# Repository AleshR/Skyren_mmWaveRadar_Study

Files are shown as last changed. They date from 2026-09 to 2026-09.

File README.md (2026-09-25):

# Skyren mmWave Radar Study

Studie proveditelnosti levného radarového dálkoměru: **vzdálenost k plošnému
cíli (kov, beton, zeď, dřevo) do 5 m s přesností kolem 5 cm při vzájemné
rychlosti až 240 m/s**, v průměru 35 mm a za jednotky eur.

Projekt začal jako teardown laserového dálkoměru Parkside PLEM 20 A4. Ten
skončil jako slepá ulička (fázový měřák s uzavřeným ASICem) a zadání na
240 m/s pak vyřadilo i optiku jako princip.

## Závěr (revize R3)

- **24 GHz FMCW s trojúhelníkovou rampou**, jedna anténa přes Ø 35 mm
  a tištěná hyperbolická čočka (svazek ~22°, zisk ~16 dBi).
- Integrovaný radarový čip ICLegend S3KM111L z levných modulů →
  materiál **~4–7 € na kus** (cena čipu neověřená).
- **Hladké plochy** (plech, hladký beton, hoblované dřevo): chyba pod 1 cm,
  měří se kolmá vzdálenost k rovině.
- **Drsné plochy** (hrubý beton, cihla): rozhoduje speckle. Po průměrování
  přes 1,2 m přiblížení ~3 cm kolmo, ~5–6 cm při náklonu 15°.
- Vysílací výkon omezuje EIRP 20 dBm → s čočkou nejvýš 4 dBm.
- **Rozbor modulů z fotek** (LD2450, LD2451): radarový čip LD2450 nese potisk
  Hi-Link, ne ICLegend — typ čipu zatím nepotvrzený. Vysílač a přijímač
  LD2450 leží ~23 mm od sebe, jedna čočka nad oběma by ztratila ~20 dB.
- **Vývojová platforma:** LD2450 s čočkou jen nad přijímačem (konfigurace B)
  — stejný rozpočet výkonu jako cílový návrh, vyzářený výkon beze změny.
- **Praktický plán** v osmi etapách s kritérii a měřicím protokolem;
  rozhodují dvě brány: ovládnout čip vlastním firmwarem a změřit speckle
  na skutečné zdi.

Čísla pocházejí z výpočtů, simulací a fotografií, ne z měření radarem.

## Co je kde

| Cesta | Obsah |
|---|---|
| `docs/mmwave_radar_study.tex` | studie, zdroj |
| `docs/mmwave_radar_study.pdf` | vysázený dokument |
| `docs/template/` | submodul — publikační systém Skyren (`skyren.cls`) |
| `docs/datasheet/` | manuály výrobce HLK-LD2450 a HLK-LD2451 (v1.0) |
| `docs/fig/` | výřezy fotek modulů pro sazbu (JPEG z `img/`) |
| `hw/lens/lens_24ghz.scad` | parametrický model 24GHz hyperbolické čočky (OpenSCAD), i dělená a seříznutá varianta pro LD2450 |
| `sim/` | simulace v čistém Pythonu: interpolace vrcholu FFT, speckle na drsné zdi |
| `img/` | fotky: teardown Parkside PLEM 20 A4 (`IMG_2014`–`2018`), HLK-LD2450 a LD2451 (`IMG_2152`–`2155`) |

STL z `.scad` se generují lokálně a do gitu nepatří:

```bash
/Applications/OpenSCAD.app/Contents/MacOS/OpenSCAD -D n=1.62 -o lens_24ghz_PETG.stl hw/lens/lens_24ghz.scad
```

Varianty pro LD2450 (díl Rozbor, konfigurace B a C):

```bash
/Applications/OpenSCAD.app/Contents/MacOS/OpenSCAD -D n=1.62 -D cut=12 -o lens_24ghz_PETG_rx.stl hw/lens/lens_24ghz.scad
/Applications/OpenSCAD.app/Contents/MacOS/OpenSCAD -D n=1.62 -D sep=23 -o lens_24ghz_PETG_split.stl hw/lens/lens_24ghz.scad
```

## Simulace

```bash
python3 sim/interpolace.py
python3 sim/speckle.py 400
python3 sim/speckle_prumer.py 100
```

## Sazba

Vyžaduje LuaLaTeX (třída používá `fontspec`). Symlinky `docs/skyren.cls`
a `docs/fonts` ukazují do submodulu, takže se překládá přímo v `docs/`:

```bash
git submodule update --init --recursive
cd docs && lualatex mmwave_radar_study.tex && lualatex mmwave_radar_study.tex
```

Dvakrát kvůli obsahu a živému záhlaví.

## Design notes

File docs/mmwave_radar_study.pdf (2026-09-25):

SKYREN ENGINEERING

TECHNICKÁ STUDIE

# Levný radarový dálkoměr pro rychlé cíle

## Od rozebraného laserového dálkoměru k 24GHz FMCW senzoru o průměru 35 mm za jednotky eur

PRO KOHO

Vývojář elektroniky nebo konstruktér se základy vysokofrekvenční techniky (návrh patch antén, vedení, polarizace), který radar dosud nenavrhoval. Tři teoretické díly (signál, odraz, anténa) vysvětlují látku od základů i s odvozením; kdo ji zná, může číst jen souhrny na začátku a na konci dílů a pokračovat dílem Návrh.

PROJEKT
mmWave Radar

REVIZE
R3

DATUM
Září 2026

KLASIFIKACE
Interní

Skyren Engineering • 2026

MMWAVE RADAR STUDY | OBSAH

SHRNUTÍ

Vzdálenost k plošnému cíli do 5 m při vzájemné rychlosti až 240 m/s změří 24GHz

FMCW radar s trojúhelníkovou rampou, jednou anténou o průměru 35 mm a tiště-

nou čočkou za zhruba 4–7 € materiálu. Hladké povrchy změří pod 1 cm; na drsných

rozhoduje speckle — po průměrování přes 1,2 m přiblížení kolem 3 cm u kolmé zdi a 5–6 cm při náklonu 15◦
, kde zadání 5 cm splní až užší svazek. Fotky modulů HLK-

LD2450 a LD2451 ukázaly, že radarový čip nese potisk Hi-Link a že vysílač a přijímač

LD2450 leží 23 mm od sebe; vývoj proto poběží s čočkou jen nad přijímačem, která dá

stejný rozpočet výkonu jako cílový návrh. Praktický díl to převádí na osm etap s kritérii;

rozhodují dvě — ovládnout čip vlastním firmwarem a změřit speckle na skutečné zdi.

INFO JAK ČÍST TENTO DOKUMENT

Boxy se štítkem označují typ sdělení: poznámka kontext navíc, tip zkratku, úskalí častou chybu, pozor nevratný krok, příklad konkrétní výpočet. Na jeden pohled otevírá díl, co z toho plyne ho uzavírá. Mono písmo značí hodnotu nebo označení dílu, číslo v kroužku 1 součástku na fotce modulu. Revize R3 doplňuje R2 o rozbor modulů HLK z fotografií (díl Rozbor) a o praktický plán (díl Praxe), který nahradil dřívější Postup. Čísla v R3 pocházejí z výpočtů, simulací a fotografií, ne z měření radarem.

## OBSAH

Východiska — Zadání a proč ne optika | 5
2 Co jsme rozebrali | 5
3 Zadání | 6
4 Co udělá rychlost 240 m/s | 6
5 Proč ne optika | 7

MMWAVE RADAR STUDY | OBSAH
Teorie: signál — Signál FMCW | 8
7 Chirp a rozdílová frekvence | 8
8 Od vzorků ke vzdálenosti | 9
9 Rozlišení a přesnost | 10
10 Dopplerův posuv a trojúhelníková rampa | 10
11 Šum a odstup signálu od šumu | 11
12 Blízký dosah: vazba, blikavý šum a horní propust | 12
Teorie: odraz — Odraz od plošného cíle | 13
14 Tři modely odrazu | 13
15 Hladký, nebo drsný? | 14
16 Zrcadlový odraz měří kolmou vzdálenost | 14
17 Stopa svazku a posun odhadu | 15
18 Speckle | 16
19 Tenké dielektrické desky | 17
Teorie: anténa — Anténa a čočka | 18
21 Apertura, svazek a zisk | 18
22 Hyperbolická čočka | 19
23 Ztráty, odrazy a protiodrazná vrstva | 20
24 Buzení mimo osu a přesah | 20
25 Vyzářený výkon | 20

MMWAVE RADAR STUDY | OBSAH
Návrh — Doporučené řešení | 22
27 Blokové schéma | 22
28 Profil vysílání | 23
29 Rozpočet výkonu | 23
30 Rozpočet chyby | 24
31 Čočka | 25
32 Cena | 25
Rozbor — Co je uvnitř modulů HLK | 27
34 Co a jak jsme fotili | 27
35 LD2450: strana antén | 27
36 LD2450: strana součástek | 28
37 LD2451: dvě řady po osmi ploškách | 30
38 Co z toho plyne pro čočku | 32
Praxe — Od modulu k prototypu | 34
40 Plán a brány | 34
41 Pracoviště a vybavení | 35
42 Pravidla pro vysílání při vývoji | 36
43 Etapa 1: oživení s původním firmwarem | 36
44 Etapa 2: mapování desky | 37
45 Etapa 3: firmware a inicializace čipu | 38

MMWAVE RADAR STUDY | OBSAH
46 Etapa 4: surová data a kalibrace vzdálenosti | 39
47 Etapa 5: čočka a svazek | 39
48 Etapa 6: přesnost na plošných cílech | 40
49 Etapa 7: pohyb, Doppler a časování | 41
50 Etapa 8: rozhodnutí o vlastní desce | 42
PŘÍLOHA — Měřicí protokol | 43
PŘÍLOHA — Přehled vzorců | 45
PŘÍLOHA — Zvažované a zamítnuté varianty | 47
PŘÍLOHA — Zdroje a vstupní data | 49
PŘÍLOHA — Slovníček pojmů | 51

MMWAVE RADAR STUDY | CO JSME ROZEBRALI
Východiska | VÝKLAD

# Zadání a proč ne optika

BOLT NA JEDEN POHLED

Rozebraný Parkside PLEM 20 A4 je fázový měřák s uzavřeným ASICem— slepá ulička. Zadání 240 m/s pak vyřadilo optiku jako princip: limitem přestává být přesnost jednoho měření a stává se jím vzorkovací frekvence. Rozhodující pro návrh jsou ale až další dvě podmínky — cena a velikost.

## 2 CO JSME ROZEBRALI

Teardown laserového dálkoměru Parkside a důvod, proč se v něm nedá pokračovat.

Výchozím bodem byl rozebraný dálkoměr Parkside PLEM 20 A4 (model HG06724, výroba 2020/06). Měřicí modul je samostatná deska zhruba 13 × 25 mm: laserová dioda v pouzdře TO, přijímací lavinová fotodioda ve stíněné komoře, krystal a jeden ASIC v pouzdře QFN s potiskem LGSM4 / N1PA45.00-24. K hlavní desce vede osmipinový plochý spoj.

Přístroj neměří dobu letu pulzu, ale fázový posuv spojitě modulovaného svazku. Celý měřicí řetězec je uvnitř ASICu se zákaznickým označením bez veřejného datového listu. Odposlech plochého spoje by dal kontrolu nad rozhraním, ne nad měřením: frekvence i integrační čas zůstávají zadrátované v čipu. Radarové moduly HLK, na kterých stojí další vývoj, rozebírá díl Rozbor.

MMWAVE RADAR STUDY | CO UDĚLÁ RYCHLOST 240 M/S

## 3 ZADÁNÍ

Pět požadavků. Poslední dva, cena a velikost, rozhodly o návrhu nejvíc.

Zadání se během studie zpřesňovalo. Tabulka uvádí jeho konečný stav:

PARAMETR | HODNOTA | POZNÁMKA
Cíl | jeden, plošný | kov, plech, beton, zeď,
| | dřevo
Přesnost | ≈ 5 cm na 5 m | rozšíření: < 3 cm do 30 m
Rychlost | až 240 m/s | vzájemná, cíl se přibližuje
Cena | ideálně 25 €, max. 50 € | materiál na kus; priorita
| | č. 1
Velikost | kruh ∅ 35 mm, co nejmenší | priorita č. 2

Tabulka 1: Konečné zadání. Cena a velikost jsou priority, které určil zadavatel.

Důležité je, že jde o jeden cíl. Nepotřebujeme oddělit dva odrazy blízko sebe (rozlišení), stačí přesně určit polohu jednoho (přesnost). Teoretické díly ukazují, že přesnost může být o řád lepší než rozlišení.

## 4 CO UDĚLÁ RYCHLOST 240 M/S

Převod rychlosti na požadavek na vzorkovací frekvenci.

Mezi dvěma vzorky urazí cíl dráhu, kterou žádné přesnější měření neodstraní— jen vyšší frekvence:

VZORKOVACÍ FREKVENCE | PERIODA | DRÁHA MEZI VZORKY
100 Hz | 10 ms | 2,40 m
1 kHz | 1 ms | 24 cm
4 kHz | 250 µs | 6 cm
10 kHz | 100 µs | 2,4 cm

Tabulka 2: Dráha mezi dvěma vzorky při 240 m/s.

Z toho plynou tři požadavky: vzorkovací frekvence aspoň 1 kHz, integrační čas jednoho měření pod 1 ms a latence celé cesty v jednotkách milisekund. Měření staré 5 ms je 1,2 m mimo.

MMWAVE RADAR STUDY | PROČ NE OPTIKA

Times PŘESNOST Z DATOVÉHO LISTU NESTAČÍ

Údaj „± 3 cm“ v datovém listu popisuje rozptyl jednoho měření za ideálních podmínek. Při 240 m/s bývá větší chybou stáří vzorku. Tu datový list neuvede, protože závisí na vaší rychlosti — spočítejte ji z frekvence a latence.

## 5 PROČ NE OPTIKA

Jediný vyhovující optický dálkoměr je o řád dražší, než dovoluje rozpočet.

Přímé měření doby letu (dToF) splní požadavek na frekvenci jen u výjimek. LightWare SF30/D měří katalogově 0,2 až 200 m s frekvencí až 20 000 měření za sekundu. Rychlostí by zadání splnil, cenou ale patří mezi měřicí techniku, ne mezi součástky. Levné senzory (VL53Lxx, TMF8828, TF-Luna) běží na desítkách až stovkách Hz. Broadcom AFBR-S50MV85G zvládne až 3000 snímků za sekundu, ale dosah má kolem 10 m. S rozpočtem 25 € proto zbývá radar.

Flag-checkered CO Z TOHO PLYNE

Optika na tomhle zadání neselhala na přesnosti, ale na kombinaci frekvence a ceny. O dalším návrhu rozhodly cena a velikost, ne fyzikální meze měření.

MMWAVE RADAR STUDY | CHIRP A ROZDÍLOVÁ FREKVENCE
Teorie: signál | VÝKLAD

# Signál FMCW

BOLT NA JEDEN POHLED

FMCW převádí vzdálenost na kmitočet. Vzdálenost vypadne z polohy vrcholu ve spektru jedné rampy; rozlišení určuje šířka pásma, přesnost odstup signálu od šumu. Pohyb cíle posune odhad o desítky centimetrů, trojúhelníková rampa ten posuv vyruší. U blízkých cílů rozhoduje vazba vysílače do přijímače a blikavý šum.

## 7 CHIRP A ROZDÍLOVÁ FREKVENCE

Model signálu, ze kterého plyne všechno ostatní.

FMCW(frequency-modulated continuous wave) vysílá spojitý signál, jehož kmitočet lineárně roste; jedné takové rampě se říká chirp. Se sklonem S = B/T, kde B je šířka přeladění a T délka chirpu, má vysílaný signál fázi

ϕt(t) = 2π

f0t +

1/2 St²

Odraz od cíle ve vzdálenosti R přijde zpožděný o dobu letu τ = 2R/c. Směšovač vynásobí vyslaný a přijatý signál a dolní propust nechá jen rozdílovou složku:

sb(t) = A cos

2πSτ t + 2πf0τ − πSτ ²

Je to harmonický signál s rozdílovou frekvencí

fb = Sτ =

2RB
cT

a s fází 4πR/λ, která se mění už při posunu cíle o zlomek vlnové délky. Člen πSτ ² je na 5 m
pod 0,1 rad a konstantní, takže ho lze zanedbat.

MMWAVE RADAR STUDY | OD VZORKŮ KE VZDÁLENOSTI

čas

kmitočet

fb

τ

B

vyslaný chirp | přijatý odraz

Obr. 1 Princip FMCW. Vyslaný chirp (plná čára) stoupá lineárně; odraz (čárkovaně) je jeho kopie posunutá o dobu letu τ . Svislá vzdálenost mezi čarami je rozdílová frekvence fb — po celou rampu konstantní a přímo úměrná vzdálenosti cíle.

Na obr. 1 je vidět, že rozdíl mezi čarami je po celou rampu konstantní. Pro návrhový profil (B = 250 MHz, T = 10 µs) vychází fb na 1 m 167 kHz, na 5 m 833 kHz a na 8 m 1,33 MHz.

## 8 OD VZORKŮ KE VZDÁLENOSTI

Okno, FFT, doplnění nulami a interpolace vrcholu — a kolik která část přispívá k chybě.

Mezifrekvenční signál se během chirpu navzorkuje; při 4 MSPS a 10 µs to je N = 40 vzorků. Vzorkování I/Q (dva kanály posunuté o 90◦
) dává komplexní signál, který rozliší znaménko kmitočtu. To je potřeba pod 0,23 m, kde dopplerovský posuv převýší rozdílovou frekvenci (viz dále).

Vzorky se vynásobí oknem. Hannovo okno potlačí postranní laloky spektra na −31 dB, takže silná vazba vysílače do přijímače nebo druhý odraz neprosáknou do buňky cíle. Cenou je dvakrát širší hlavní lalok a šumová šířka 1,5 buňky místo jedné.

Pak následuje rychlá Fourierova transformace (FFT). Doplnění nulami ze 40 na 64 nebo 128 bodů zhustí vzorkování spektra, rozlišení ale nezlepší. Vrchol leží mezi body FFT; jeho polohu dopočítá parabolická interpolace logaritmu amplitudy ve třech bodech k − 1, k, k + 1 s hodnotami α, β, γ v dB:

δ =

1
2

·

α − γ
α − 2β + γ

, Rˆ = (k + δ) ·

c fs
2 S M
kde fs je vzorkovací frekvence a M délka FFT. Simulace s Hannovým oknem dala systematickou chybu interpolace nejvýš 2 mm pro M = 64 a 0,2 mm pro M = 128. Interpolace tedy do rozpočtu chyby nepřispívá.

MMWAVE RADAR STUDY | DOPPLERŮV POSUV A TROJÚHELNÍKOVÁ RAMPA

## 9 ROZLIŠENÍ A PŘESNOST

Rozlišení určuje šířka pásma, přesnost na jeden cíl určuje odstup signálu od šumu.

Rozlišení je nejmenší vzdálenost, na které radar oddělí dva cíle. Závisí jen na šířce přeladění:

∆R =

c
2B
Ve volném pásmu 24,00--24,25 GHz je B = 250 MHz, takže ∆R = 60 cm. Lepší rozlišení by vyžadovalo jiné pásmo: 4 GHz v pásmu 60 GHz dává 3,75 cm.

Pro jeden cíl je podstatnápřesnost. Teoretickou nejmenší chybu udáváCramér–Raovamez pro odhad kmitočtu harmonického signálu v šumu:

σR ≥

√
6
2π

·

∆R
√
SNR

≈ 0,39

∆R
√
SNR

kde SNR je odstup signálu od šumu po FFT (energie signálu za chirp k spektrální hustotě šumu). Hannovo okno s parabolickou interpolací dosahuje podle simulace σR ≈ 0,6 ∆R/

√
SNR.

TERMINAL PŘÍKLAD

Buňka 60 cm, SNR 30 dB (1000×): mez dává 0,74 cm, praktický odhad 1,1 cm, simulace 1,2 cm. Při 40 dB vychází prakticky 0,35 cm. Rozlišení 60 cm tedy přesnosti na centimetry nebrání, pokud je signálu dost a cíl je jeden.

Fáze vrcholu 4πR/λ nese ještě jemnější informaci, ale s nejednoznačností λ/2, na 24 GHz 6,2 mm. Hrubý odhad z FFT není dost přesný, aby ji rozbalil absolutně. Fáze proto dává jen relativní změnu vzdálenosti při spojitém sledování cíle.

## 10 DOPPLERŮV POSUV A TROJÚHELNÍKOVÁ RAMPA

Při 240 m/s posune pohyb cíle odhad o 23 cm. Střídání rampy nahoru a dolů ten posuv vyruší a navíc změří rychlost.

Přibližující se cíl zvýší kmitočet odrazu o dopplerovský posuv fd = 2v/λ; při 240 m/s a λ = 12,4 mm to je 38,6 kHz. U stoupající rampy se tím rozdílová frekvence zmenší, u klesající zvětší:
fb↑ = Sτ − fd, fb↓ = Sτ + fd

Převedeno na vzdálenost je každý z obou odhadů posunutý o

∆RD = | v c T λ B

což je při chirpu 10 µs 23 cm, při 25 µs už 58 cm.

MMWAVE RADAR STUDY | ŠUM A ODSTUP SIGNÁLU OD ŠUMU

čas

kmitočet

fb↑
fb↓
vyslaná rampa | odraz od přibližujícího se cíle

Obr. 2 Trojúhelníková rampa a přibližující se cíl. Odraz (čárkovaně) je zpožděný o τ a posunutý nahoru o fd. Na stoupající rampě se rozdílová frekvence zmenší, na klesající zvětší; průměr obou je bez Dopplerova posuvu.

Z dvojice odhadů R↑ = R − ∆RD a R↓ = R + ∆RD (obr. 2) plyne

R =

R↑ + R↓
2

, v =

λB
2cT
R↓ − R↑

Vzdálenost platí pro střed dvojice chirpů, tam patří i časová značka. Během jednoho chirpu se cíl posune o vT = 2,4 mm, což je zanedbatelné. Dopplerovská FFT přes více chirpů, obvyklá u automobilových radarů, tu nefunguje: s periodou chirpů kolem 25 µs je nejvyšší jednoznačná rychlost λ/4Tc ≈ 124 m/s a 240 m/s by se přetočila.

## 11 ŠUM A ODSTUPSIGNÁLU OD ŠUMU

Tepelný šum v šířce jedné buňky a proč fázový šum oscilátoru na metrech skoro nevadí.

Šum připadající na jednu buňku spektra je tepelný šum v šumové šířce okna, zvětšený o šumové číslo přijímače F:

N = kT0 ·

ENBW
T
- F | ⇒ | NdBm = −174 + 10 log10

1,5
T

+ FdB

Pro chirp 10 µs a šumové číslo 15 dB (odhad, datový list čipu nemáme) vychází N ≈ −107 dBm.

Fázový šum oscilátoru se ve směšovači z velké části odečte, protože vysílaný i referenční signál pocházejí ze stejného oscilátoru. Zbytek je úměrný 2 sin(πfmτ ), kde fm je odstup od nosné. Na 5 m je τ = 33 ns a potlačení vychází −14 dB při 1 MHz a −34 dB při 100 kHz. Na krátké vzdálenosti tedy kvalita oscilátoru rozhoduje málo.

MMWAVE RADAR STUDY | BLÍZKÝ DOSAH: VAZBA, BLIKAVÝ ŠUM A HORNÍ PROPUST

## 12 BLÍZKÝ DOSAH: VAZBA, BLIKAVÝ ŠUM A HORNÍ PRO-

## PUST

Silná vazba vysílače do přijímače, blikavý šum a velká dynamika se řeší jedním filtrem — a ten má mít pro plošný cíl sklon 20 dB na dekádu, ne 40.

S jednou anténou pro vysílání i příjem teče část vysílaného výkonu přímo do přijímače: přes konečnou izolaci vazebníku (typicky kolem 25 dB), přes odraz na anténě a přes odrazy na čočce. Tato vazba sedí u nulové rozdílové frekvence a může dosáhnout −15 až −20 dBm na vstupu přijímače. Kompresní bod přijímače integrovaného čipu neznáme; pokud je kolem −15 dBm, hrozí zahlcení. Proto je u jedné antény klíčové dobré impedanční přizpůsobení (S11 < −20 dB).

Blikavý šum (1/f) směšovače roste pod zhruba 100 kHz. Krátký chirp drží rozdílovou frekvenci i na 1 m (167 kHz) nad touto oblastí.

Výkon odrazu od plošného cíle klesá s R²
(díl Odraz od plošného cíle), amplituda tedy s 1/R, a protože fb ∝ R, klesá amplituda úměrně 1/fb. Horní propust prvního řádu s mezním kmitočtem nad pásmem měření má v pásmu zisk úměrný f, tedy +20 dB na dekádu: srovná úroveň signálu přes celý rozsah vzdáleností a současně potlačí vazbu u nulového kmitočtu. Pro bodový cíl (R⁻⁴
) by bylo potřeba +40 dB na dekádu.

Flag-checkered CO Z TOHO PLYNE

Vzdálenost dá jedna rampa a jedna malá FFT; interpolace vrcholu je přesná na milimetry. Dopplerův posuv 23 cm vyruší trojúhelníková rampa. Přesnost pak určuje odstup signálu od šumu — a u plošného cíle, jak ukáže další díl, hlavně geometrie odrazu.

MMWAVE RADAR STUDY | TŘI MODELY ODRAZU
Teorie: odraz | VÝKLAD

# Odraz od plošného cíle

BOLT NA JEDEN POHLED

Hladká plocha se chová jako zrcadlo: odraz přichází z malé skvrny kolem paty kolmice a radar změří kolmou vzdálenost na milimetry. Drsná plocha rozptyluje: přispívá celá stopa svazku, odhad se posune a náhodně kolísá (speckle). Rozhoduje drsnost vůči vlnové délce, ne materiál.

## 14 TŘI MODELY ODRAZU

Bodový cíl, zrcadlová plocha a drsná plocha mají tři různé radarové rovnice.

Bodový cíl s radarovým průřezem σ je výchozí případ radarové rovnice:

Pr =

Pt G²λ

2 σ
(4π)

3R⁴

Hladká rovina větší než první Fresnelova zóna se chová jako zrcadlo. Radar v ní vidí svůj obraz ve vzdálenosti 2R, takže

Pr =

Pt G²λ

2
|Γ|

2
(4π)

2(2R)

2

kde Γ je činitel odrazu materiálu. Odraz vzniká v první Fresnelově zóně, skvrně o poloměru
p

λR/2 kolem paty kolmice z radaru na rovinu. Na 5 m to je 18 cm, zatímco stopa svazku 22◦ má poloměr kolem 1 m. Zeď je tedy pro radar „nekonečné zrcadlo“.

Drsná rovina rozptyluje difúzně a každý kousek plochy přispívá podle koeficientu zpětného rozptylu σ

0

(m² na m² plochy). Efektivní průřez je σ = σ

0R²Ωef, kde Ωef je prostorový úhel svazku vážený dvoucestným diagramem; pro gaussovský svazek s šířkou θ3 platí Ωef = πθ²
3

/(8 ln 2). Protože zisk antény G ∝ 1/θ 2/3, vychází

Pr ∝

G
R²

Oba plošné případy tedy klesají s R²

, ne s R⁴
. U drsné plochy navíc větší anténa signál skoro nezlepší, protože užší svazek ozáří menší plochu.

MMWAVE RADAR STUDY | ZRCADLOVÝ ODRAZ MĚŘÍ KOLMOU VZDÁLENOST

## 15 HLADKÝ, NEBO DRSNÝ?

O chování plochy rozhoduje drsnost ve srovnání s vlnovou délkou. Na 24 GHz leží hranice kolem 1,5 mm.

Nerovnosti o střední výšce h rozfázují odražené vlny. Zrcadlová (koherentní) složka odrazu klesne podle Rayleighova kritéria o faktor

ρ = exp"
−
4πh cos θi
λ

2

kde θi

je úhel dopadu. Na 24 GHz to dává pokles o 1,1 dB při h = 0,5 mm, 4,4 dB při 1 mm, 18 dB při 2 mm a 40 dB při 3 mm. Obvyklá hranice je h ≈ λ/8 = 1,6 mm.

POVRCH | DRSNOST h | CHOVÁNÍ | |Γ| KOLMO
plech | 0,1 mm | zrcadlové | 1 (0 dB)
hladký beton, omítka | ≈ 0,5–1 mm | převážně zrcadlové | ≈ 0,40 (−8 dB)
hoblované dřevo | < 0,5 mm | zrcadlové | ≈ 0,17 (−15 dB)
sádrokarton | < 0,5 mm | zrcadlové | ≈ 0,25 (−12 dB)
řezané dřevo | ≈ 1–2 mm | smíšené | ≈ 0,17
hrubý beton, cihla, kámen | ≈ 2–5 mm | difúzní | —

Tabulka 3: Typické povrchy na 24 GHz. Drsnosti a permitivity jsou orientační hodnoty, ne měření.

Činitel odrazu při kolmém dopadu je Γ = (1 −

√

εr)/(1 + √
εr). Pro beton s εr ≈ 5,5 vychází 0,40, pro suché dřevo s εr ≈ 2 jen 0,17. Dřevo je tedy nejslabší zrcadlo, ale rozpočet výkonu v dílu Návrh ukáže, že i tak zbývá přes 40 dB odstupu od šumu.

## 16 ZRCADLOVÝ ODRAZ MĚŘÍ KOLMOU VZDÁLENOST

Hladká plocha nemá žádný posun od stopy svazku. Při náklonu ale měří jinou vzdálenost, než je vzdálenost v ose, a slábne.

Protože zrcadlový odraz přichází jen z první Fresnelovy zóny kolem paty kolmice, radar změří kolmou vzdálenost k rovině R⊥ = R cos α, kde α je náklon plochy vůči ose senzoru. Stopa svazku se neuplatní a chyba je daná jen šumem.

Při náklonu leží pata kolmice mimo osu svazku a odraz zeslábne podle dvoucestného diagramu. Pro svazek 22◦

je to −6 dB při 11◦

, −11 dB při 15◦

, −20 dB při 20◦ a −31 dB při 25◦ .

MMWAVE RADAR STUDY | STOPA SVAZKU A POSUN ODHADU

Hladký plech nakloněný o víc než zhruba 20◦ proto nevrátí skoro nic — nemá difúzní složku, která by zbyla.

INFO KTEROU VZDÁLENOST VLASTNĚ MĚŘÍME

Při náklonu 15◦
je na 5 m rozdíl mezi kolmou vzdáleností a vzdáleností v ose kolem 17 cm. Není to chyba měření. U hladkých ploch radar měří kolmou vzdálenost, u drsných zhruba vzdálenost v ose. Aplikace musí vědět, kterou z nich potřebuje.

## 17 STOPA SVAZKU A POSUN ODHADU

U drsné plochy přispívá celá stopa. Její zakřivení vůči radaru posune odhad za skutečnou vzdálenost.

radar

R

zeď

∆R

θ/2

Obr. 3 Stopa svazku na zdi (bokorys, úhel zveličený). Kružnice konstantní vzdálenosti (červeně) protíná zeď jen v ose; okraje stopy leží dál o ∆R. U drsné plochy padnou všechny příspěvky do jedné buňky a posunou odhad za kolmou vzdálenost.

Vzdálenost k bodu plochy ve směru (θx, θy) od osy je pro plochu nakloněnou o α kolem osy y přibližně
R(θx, θy) ≈ R
1 + θx tan α + θ

2
x

1

2 + tan² α
+

1/2 θ

2
y

Rozdíly vzdáleností ve stopě jsou mnohem menší než buňka 60 cm, takže vrchol FFT leží ve výkonově váženém průměru vzdáleností. Pro gaussovský dvoucestný diagram s rozptylem σ

2
θ = θ

2/3/(16 ln 2) v každé ose lineární člen vypadne a zbude posun od stopy svazku

b = R σ²
θ

(1 + tan² α) = R θ²
3
16 ln 2

(1 + tan² α)

MMWAVE RADAR STUDY | SPECKLE

(obr. 3). U kolmé zdi se simulace od vzorce liší o méně než desetinu, u nakloněné do pětiny, zčásti kvůli statistickému rozptylu simulace.

HPBW | POSUN NA 5 M | POSUN NA 30 M
42◦ | 24 cm | 1,45 m
22◦ | 6,6 cm | 40 cm
14◦ | 2,7 cm | 16 cm
10◦ | 1,4 cm | 8,2 cm

Tabulka 4: Posun odhadu od stopy svazku pro drsnou zeď kolmo k ose. Hodnota je deterministická a odečítá se kalibrací.

Posun je pro známou vzdálenost a svazek spočitatelný, takže se odečte. Náklon ho zvětší o tan² α, při 15◦ o 7 %. Zbytek po kalibraci je na 5 m se svazkem 22◦ kolem 0,5 cm z náklonu, k tomu neznámý příspěvek toho, že σ

0 závisí na úhlu dopadu a váží stopu nesymetricky. Počítáme s celkem kolem 1 cm, ale ověřené to není.

## 18 SPECKLE

Příspěvky drsné plochy se sčítají s náhodnými fázemi. Odhad vzdálenosti proto kolísá, a u nakloněné plochy hodně.

Každý kousekdrsné plochy vrací vlnu s náhodnou fází. Jejich součet má náhodnou amplitudu i náhodnou polohu vrcholu ve spektru; tomuto jevu se říká speckle. Střední hodnota odhadu je posun b z předchozí sekce, kolem ní odhad kolísá zhruba o efektivní rozptyl vzdáleností ve stopě

sR ≈ R σθ

q
σ

2

θ + tan² α

U kolmé plochy je sR = b, u nakloněné převládne lineární člen R σθ tan α a kolísání vzroste několikanásobně. Když amplituda odrazu náhodně klesne (hluboký útlum), poloha vrcholu ujede výrazně víc; takové měření je lepší zahodit.

HPBW | NÁKLON | SIMULACE | MODEL sR
22◦ | 0
| ◦ | 7,1 cm | 6,7 cm
22◦ | 15◦ | 15,8 cm | 16,8 cm
14◦ | 0
| ◦ | 3,0 cm | 2,7 cm
14◦ | 15◦ | 10,6 cm | 10,2 cm
10◦ | 0
| ◦ | 1,3 cm | 1,4 cm
10◦ | 15◦ | 7,2 cm | 7,2 cm

MMWAVE RADAR STUDY | TENKÉ DIELEKTRICKÉ DESKY

Tabulka 5: Kolísání jednoho měření na drsné zdi ve 5 m. Simulace Monte Carlo s vyřazením 10 % nejslabších měření, srovnaná s modelem.

Kolísání pomůže jen průměrování přes nezávislé realizace speckle. Při přibližování se mění relativní fáze příspěvků a nová realizace vznikne zhruba po každých

δR ≈

λR
4 sR

přiblížení, na 5 m u kolmé zdi a svazku 22◦ po 24 cm. Průměr přes dráhu přiblížení L má kolísání

σprům ≈

r
sR λR
4L
Pro L = 1,2 m (5 ms při 240 m/s) dává model 2,9 cm u kolmé zdi a 4,7 cm při náklonu 15◦ ;
simulace přibližování dala 2,3 cm a 5,8 cm.

Times PRŮMĚRUJE SE DRÁHA, NE ČAS

Speckle se obnovuje pohybem, ne časem. Při 240 m/s dá 5 ms dost nezávislých měření, při 10 m/s by stejné okno vystačilo jen na 5 cm dráhy a kolísání by zůstalo skoro celé. Když senzor stojí, je speckle zamrzlý a chyba se stane pevnou chybou daného místa. Pásmo 250 MHz je navíc příliš úzké na to, aby pomohlo střídání kmitočtu.

## 19 TENKÉ DIELEKTRICKÉ DESKY

Dřevěná deska nebo sádrokarton odrážejí z přední i zadní strany a oba odrazy padnou do jedné buňky.

Část vlny projde do materiálu s nízkou permitivitou a odrazí se od zadní strany. Ta se radaru jeví posunutá o √
εr d; pro 2cm překližku s εr ≈ 2 o 2,8 cm. Oba odrazy leží v jedné buňce a interferují podle tloušťky desky, takže vrchol se posune o část této vzdálenosti. Útlum ve vlhkém dřevě zadní odraz zeslabí. Počítáme s posunem řádově 1 cm, ověřené to není.

Flag-checkered CO Z TOHO PLYNE

Hladké plochy dávají zrcadlový odraz bez posunu od stopy: chyba pod centimetr, měřená je kolmá vzdálenost. Nejhorším cílem pro přesnost je drsná nakloněná plocha: jedno měření kolísá o 15 cm i víc a pomůže jen užší svazek a průměrování přes dráhu přiblížení.

MMWAVE RADAR STUDY | APERTURA, SVAZEK A ZISK
Teorie: anténa | VÝKLAD

# Anténa a čočka

BOLT NA JEDEN POHLED

Šířka svazku je daná průměrem apertury ve vlnových délkách, takže na 24 GHz se do ∅ 35 mm vejde jeden svazek kolem 22◦
. Plastová hyperbolická čočka ho vytvoří z malé antény levně. Zisk čočky ale omezuje vysílací výkon: vyzářený výkon v pásmu 24 GHz nesmí přesáhnout 100 mW.

## 21 APERTURA, SVAZEK A ZISK

Tři vztahy, které určují velikost senzoru.

Pro kruhovou aperturu o průměru D platí přibližně

θ3 ≈ (58 až 70) λ
D

, G ≈ η

πD
λ

2
, Rff =

2D²

λ

Šířka svazku θ3 ve stupních platí s koeficientem 58 pro rovnoměrné osvětlení, se 70 pro osvětlení klesající k okraji. Činitel využití apertury η bývá 0,5–0,6. Vzdálenost Rff je začátek dalekého pole. Pro ∅ 35 mm na 24 GHz vychází θ3 ≈ 21–23◦
, G ≈ 16 dBi a Rff ≈ 20 cm.
PÁSMO | λ | ∅ PRO 22◦ | ∅ PRO 10◦
24 GHz | 12,4 mm | ≈ 30–35 mm | ≈ 75 mm
60 GHz | 5,0 mm | ≈ 10–12 mm | ≈ 30–35 mm

Tabulka 6: Průměr apertury podle pásma a požadované šířky svazku.

Do ∅ 35 mm se tedy na 24 GHz vejde právě jeden svazek kolem 22◦
. Proto návrh používá
jednu anténu pro vysílání i příjem. Dvě antény vedle sebe by měly svazek zhruba 23×42◦ a podle tabulky posunů v dílu Odraz od plošného cíle několikanásobně větší posun i kolísání. Svazek 10◦
, který by pomohl na drsných nakloněných plochách, se do ∅ 35 mm vejde jen na 60 GHz.

MMWAVE RADAR STUDY | HYPERBOLICKÁ ČOČKA

## 22 HYPERBOLICKÁ ČOČKA

Tvar plochy plyne z Fermatova principu: všechny paprsky z ohniska musí mít za čočkou stejnou optickou dráhu.

Zdroj leží v ohnisku ve vzdálenosti f před vrcholem čočky. Paprsek, který dopadne na plochu v bodě (x, r), má urazit stejnou optickou dráhu jako paprsek v ose, aby za rovnou plochou vyšla rovinná vlna. Uvnitř materiálu s indexem lomu n se dráha násobí n, takže

p
x

2 + r

2 = f + n (x − f)

Po dosazení x = f + z, kde z je výška profilu nad vrcholem, vyjde

r

2 = 2 (n − 1) f z + (n

2 − 1) z

2

tedy hyperbola. Parametrický model podle tohoto vztahu je v hw/lens/lens_24ghz.scad.

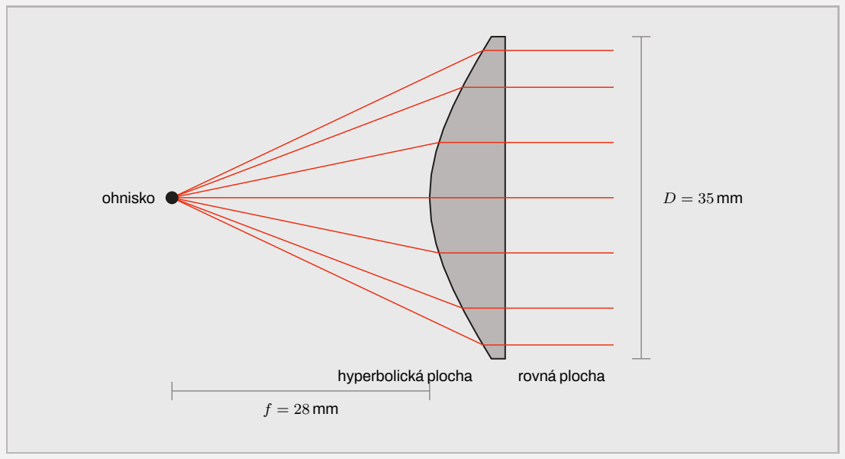
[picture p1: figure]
ohnisko; hyperbolická plocha; rovná plocha

Obr. 4 Hyperbolická čočka z PETG (n = 1,62, f = 28 mm, ∅ 35 mm), zvětšeno. Paprsky z ohniska se na hyperbolické ploše lámou tak, že za čočkou běží rovnoběžně.

Obr. 4 ukazuje hlavní vlastnost: hyperbolická plocha míří k anténě, rovná plocha k cíli. Fázový střed antény musí ležet přesně v ohnisku. Posun o pár milimetrů podél osy svazek rozostří, posun napříč ho vychýlí.

MMWAVE RADAR STUDY | VYZÁŘENÝ VÝKON

## 23 ZTRÁTY, ODRAZY A PROTIODRAZNÁ VRSTVA

Tištěný plast má na 24 GHz zanedbatelné ztráty. Víc vadí odrazy na plochách, které se vracejí do přijímače.

Na každé ploše se odrazí podíl výkonu

|Γ|

2 =

n − 1

n + 12

pro PETG 5,6 % (−12,5 dB), což dělá 0,25 dB ztráty na plochu. Odražená vlna se vrací do antény a přidá se k vazbě vysílače do přijímače. Dielektrické ztráty jsou

αdB ≈ 27,3

n tan δ
λ0
na jednotku délky; pro PETG s tan δ ≈ 0,01 (odhad) to je 0,036 dB/mm, ve středu čočky tlusté 8 mm tedy kolem 0,3 dB.

Odrazy odstraní protiodrazná vrstva tloušťky λ0/4nm s indexem lomu nm =

√
n. Pro PETG
vychází nm = 1,27 (εr = 1,62) a tloušťka 2,4 mm. Tisk nabízí levný trik: vrstvu vytisknout se sníženou výplní. Při lineárním směšování permitivit s vzduchem odpovídá εr = 1,62 výplni kolem 38 %. Je to orientační výpočet; skutečnou permitivitu je třeba změřit.

## 24 BUZENÍ MIMO OSU A PŘESAH

Anténa mimo ohnisko vychýlí svazek; záření, které čočku mine, svítí do stran.

Posune-li se fázový střed antény o d napříč osou, svazek se vychýlí zhruba o úhel d/f na opačnou stranu. U modulu s oddělenou vysílací a přijímací anténou se tak jejich svazky pod jednou čočkou rozejdou. Při rozestupu 10 mm a f = 28 mm to je ± 10◦
: společný svazek se
zúží a ztratí několik dB. LD2450 má rozestup 23 mm (díl Rozbor), tedy kolem ± 20◦ a ztrátu kolem 20 dB. Na vlastní desce s jednou anténou tento problém odpadá.

Okraj čočky vidí anténa pod úhlem arctan(D/2f) = 32◦
. Co vyzáří pod větším úhlem, čočku mine (přesah) a svítí do stran, kde vrací odrazy od bližších ploch. Mezi anténu a čočku proto patří trubka, zevnitř vodivá nebo s absorbérem.

## 25 VYZÁŘENÝ VÝKON

Zisk čočky se počítá do vyzářeného výkonu. S 16 dBi smí vysílač dávat nejvýš 4 dBm.

V pásmu 24,00–24,25 GHz je pro zařízení krátkého dosahu povolený ekvivalentní izotropně vyzářený výkon (EIRP) 100 mW, tedy 20 dBm (ERC/REC 70-03, příloha 1; aktuální znění je

MMWAVE RADAR STUDY | VYZÁŘENÝ VÝKON

třeba ověřit). EIRP je součet vysílacího výkonu a zisku antény, takže s čočkou 16 dBi smí vysílač dávat nejvýš 4 dBm. Hotový modul, který je certifikovaný s vlastní anténou, může po přidání čočky limit překročit. Vysílací výkon je pak nutné ve firmwaru snížit. Rozpočet výkonu v dílu Návrh už s 4 dBm počítá.

Flag-checkered CO Z TOHO PLYNE

Čočka ∅ 35 mm dá na 24 GHz svazek kolem 22◦ a zisk 16 dBi za cenu plastu. Její tvar plyne přímo z Fermatova principu, ztráty jsou zanedbatelné a odrazy lze potlačit vrstvou s řidší výplní. Zisk ale snižuje povolený vysílací výkon na 4 dBm.

MMWAVE RADAR STUDY | BLOKOVÉ SCHÉMA
Návrh | REFERENCE

# Doporučené řešení

BOLT NA JEDEN POHLED

Pásmo 24 GHz, jedna anténa s čočkou ∅ 35 mm, integrovaný radarový čip s trojúhelníkovou rampou a levný mikrokontrolér. Tabulky uvádějí profil vysílání, rozpočet výkonu, rozpočet chyby, čočku a cenu. Hodnoty čipu, které nejsou ověřené, jsou takto označené.

## 27 BLOKOVÉ SCHÉMA

Čtyři bloky: čočka s anténou, vazebník, radarový čip a mikrokontrolér.

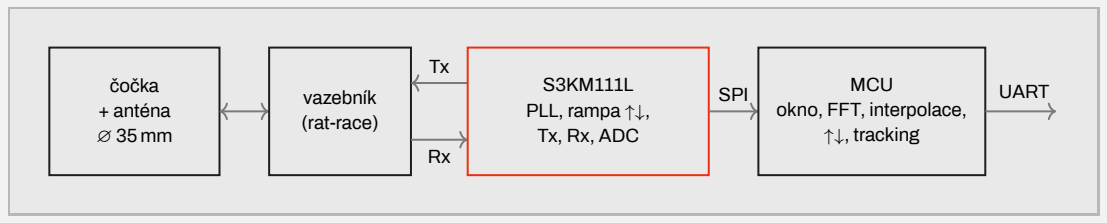
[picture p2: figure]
čočka + anténa ∅ 35 mm; vazebník (rat-race); S3KM111L PLL, rampa ↑↓, Tx, Rx, ADC; SPI; MCU; okno, FFT, interpolace, ↑↓, tracking; UART

Obr. 5 Blokové schéma senzoru. Vazebník spojuje vysílač a přijímač čipu do jedné antény; čip vzorkuje mezifrekvenční signál a mikrokontrolér z něj počítá vzdálenost.

Obr. 5 ukazuje cílovou vlastní desku. Při vývoji na hacknutém modulu LD2450 místo vazebníku a jedné antény slouží jeho oddělené antény a čočka sedí jen nad přijímačem (díl Rozbor, konfigurace B).

MMWAVE RADAR STUDY | ROZPOČET VÝKONU

## 28 PROFIL VYSÍLÁNÍ

Cílový profil pro dosah do 5 m.

PARAMETR | HODNOTA | DŮVOD
Šířka přeladění | 250 MHz | celé volné pásmo 24 GHz
Rampa | trojúhelníková | vyruší Dopplerův posuv
Délka chirpu | 10 µs | fb nad pásmem blikavého
| | šumu
fb na 1 / 5 / 8 m | 167 kHz / 833 kHz /
| 1,33 MHz
Vzorkování | 4 MSPS, I/Q | 40 vzorků, Hann, FFT 64
| | nebo 128
Vysílací výkon | ≤ 4 dBm | EIRP 20 dBm se ziskem
| | 16 dBi
Výstup | 1 měření na pár chirpů | 4–10 kHz podle čipu a MCU

Tabulka 7: Cílový profil. Zda ho integrovaný čip umí nastavit, zejména délku chirpu, zatím nevíme.

Integrovaný čip ICLegend S3KM111L podle databriefu umí trojúhelníkovou rampu a až 8 000 chirpů za sekundu, tedy kolem 4 kHz měření. Pokud ale nepodporuje chirp výrazně kratší než periodu 125 µs, klesne rozdílová frekvence na 1 m na desítky kHz a měření pod 1–2 m se zhorší. Na 5 m to nevadí.

## 29 ROZPOČET VÝKONU

Na 5 m je signálu dost i pro nejslabší povrch.

CÍL | PŘIJATÝ VÝKON | SNR PO FFT
plech, zrcadlově | −51 dBm | 56 dB
hladký beton, zrcadlově | −59 dBm | 48 dB
sádrokarton, zrcadlově | −63 dBm | 44 dB
suché dřevo, zrcadlově | −66 dBm | 41 dB
drsný povrch, σ
0 = −10 dB | −77 dBm | 30 dB
drsný povrch, σ
0 = −20 dB | −87 dBm | 20 dB

Tabulka 8: Rozpočet výkonu na 5 m. Vysílač 4 dBm, čočka 16 dBi, vazebník 3,5 dB v každém směru, šum −107 dBm na buňku (šumové číslo 15 dB je odhad).

MMWAVE RADAR STUDY | ROZPOČET CHYBY

Mezi nejsilnějším případem (plech zblízka) a nejslabším (drsný povrch na 5 m) je přes 60 dB. K tomu vazba vysílače do přijímače kolem −15 dBm. Proto horní propust s +20 dB na dekádu a podle potřeby řízení zesílení.

## 30 ROZPOČET CHYBY

Na hladkých plochách pod centimetr, na drsných rozhoduje speckle a průměrování přes dráhu přiblížení.

ZDROJ CHYBY | HLADKÝ | DRSNÝ, KOLMO | DRSNÝ, 15◦
šum, jedno měření | 0,1–0,4 cm | 1,9 cm | 1,9 cm
posun od stopy po kalibraci | 0 | ≈ 1 cm | ≈ 1–1,5 cm
speckle, jedno měření | 0 | 7 cm | 16 cm
Dopplerův posuv po průměru ramp | ≈ 0 | ≈ 0 | ≈ 0

celkem, jedno
měření
< 0,5 cm | ≈ 7 cm | ≈ 16 cm

celkem po
průměrování
< 0,5 cm | ≈ 3 cm | ≈ 5–6 cm

Tabulka 9: Rozpočet chyby na 5 m se svazkem 22◦ . Hodnoty „po průměrování“ platí pro průměr přes 1,2 m přiblížení (5 ms při 240 m/s), šum pro drsný povrch s σ

0 = −15 dB. Jde o výpočty a simulace, ne o měření.

Zadání 5 cm tedy splní hladké plochy vždy a drsné plochy kolmo k ose po průměrování. Drsná plocha nakloněná o 15◦ vychází na hranici. Pomohl by užší svazek (s 10◦ vychází model na 3 cm), ten se ale do ∅ 35 mm na 24 GHz nevejde. Druhou možností je delší dráha průměrování, pokud to aplikace dovolí.

MMWAVE RADAR STUDY | CENA

## 31 ČOČKA

Parametry pro tisk a obrábění.

MATERIÁL | n | TLOUŠŤKA VE
| | STŘEDU

VÝŠKA OD ANTÉNY

HDPE | 1,52 | 9,3 mm | 37 mm
PTFE | 1,45 | 10,3 mm | 38 mm
PETG (tisk, 100 % výplň) | ≈ 1,62 | 8,2 mm | 36 mm
PLA (tisk, 100 % výplň) | ≈ 1,65 | 7,9 mm | 36 mm

Tabulka 10: Čočka ∅ 35 mm, ohnisková vzdálenost 28 mm, okraj 1,5 mm. Indexy lomu tištěných plastů jsou orientační.

Očekávaná šířka svazku je 21–23◦
, zisk kolem 16 dBi a daleké pole začíná zhruba ve 20 cm. Pro první prototypy stačí tisk z PETG; pro další iterace je lepší HDPE se známými vlastnostmi a nulovými ztrátami.

## 32 CENA

Materiál na kus při 500 kusech. Rozhoduje radarový čip.

VARIANTA | RADAROVÝ ČIP | CELKEM

Integrovaný SoC
(doporučeno)

S3KM111L, ≈ 1–2 €
(neověřeno)

≈ 4–7 €

Záloha s vlastním
front-endem
| BGT24MTR11, ≈ 10 € | ≈ 15 €

60 GHz s anténou
v pouzdře
| Acconeer A121, ≈ 9 $ | ≈ 10–12 €

Tabulka 11: Varianty materiálu na kus. Cena čipu S3KM111L je odhad z cen hotových modulů, ne nabídka.

Integrovaný čip obsahuje vysílač, přijímač, PLL, generátor rampy a ADC, takže odpadá rychlý ADC, generátor rampy i teplotně kompenzovaný krystal. Rampa z PLL je lineární, takže odpadá i kalibrace linearity při výrobě. Stačí levnýmikrokontrolér, který přijímá data a počítámalé

MMWAVE RADAR STUDY | CENA

FFT. Anténa může být na FR4 nebo levném PTFE laminátu F4B: ztráty 2–3 dB a rozladění kvůli toleranci permitivity jsou při rezervě přes 20 dB přijatelné.

Kterou vzdálenost potřebuješ?

v ose senzoru | k nejbližšímu povrchu

úzký svazek ≈ 22◦

24 GHz + čočka ∅ 35, 4–7 €

široký svazek stačí

A121 bez čočky, ≈ 8×8 mm

Obr. 6 Volba varianty. O velikosti rozhoduje, kterou vzdálenost aplikace potřebuje.

Široký svazek přirozeně měří nejbližší bod plochy. Pokud aplikaci stačí nejkratší vzdálenost k povrchu, úzký svazek není potřeba a velikost určí jen čip (obr. 6). Pro nejbližší bod je ale potřeba jemné rozlišení, aby šla přesně najít náběžná hrana odrazu — proto v pravé větvi 60 GHz, ne 24 GHz s buňkou 60 cm.

Flag-checkered CO Z TOHO PLYNE

Doporučená varianta stojí na integrovaném 24GHz čipu za jednotky eur, jedné anténě přes ∅ 35 mm a tištěné čočce. Na hladkých plochách měří pod centimetr, na drsných kolmých po průměrování kolem 3 cm. Drsné nakloněné plochy a rozšíření na 3 cm do 30 m potřebují užší svazek, v tomto průměru tedy 60 GHz.

MMWAVE RADAR STUDY | LD2450: STRANA ANTÉN
Rozbor | VÝKLAD

# Co je uvnitř modulů HLK

BOLT NA JEDEN POHLED

Fotky obou stran HLK-LD2450 a HLK-LD2451 potvrdily uspořádání 1T2R a pouzdro QFN-32, ne ale typ čipu: radarový čip LD2450 nese potisk Hi-Link. Vysílač a přijímač LD2450 leží 23 mm od sebe, takže jedna čočka nad oběma by ztratila kolem 20 dB. Čočka jen nad přijímačem dá naopak stejný rozpočet výkonu jako cílový návrh a nemění vyzářený výkon.

## 34 CO A JAK JSME FOTILI

Rozměry pocházejí z fotografií, ne z měřidla. Nejistota je kolem 5 %, u rozestupu antén tedy ± 1 mm.

Oba moduly jsme nafotili telefonem shora, každý z obou stran (snímky IMG_2152 až IMG_2155 ve složce img/, výřezy pro sazbu v docs/fig/). Měřítko dává obrys desky podle rozměrů výrobce, 44 × 15 mm u LD2450 a 70 × 35 mm u LD2451; u LD2450 vychází kolem 40 obrazových bodů na milimetr. Nejistotu přidává perspektiva a zaoblené rohy desky.

Potisky čipů jsou vypálené laserem a v rovném světle skoro splývají s pouzdrem. Čitelný byl jen potisk radarového čipu LD2450, a to až po otočení výřezu a zvýšení kontrastu. Ostatní přečte až makrosnímek s bočním světlem (díl Praxe, etapa 2).

## 35 LD2450: STRANA ANTÉN

Jeden vysílač a dva přijímače po dvou ploškách, mezi nimi radarový čip s potiskem Hi-Link.

MMWAVE RADAR STUDY | LD2450: STRANA SOUČÁSTEK

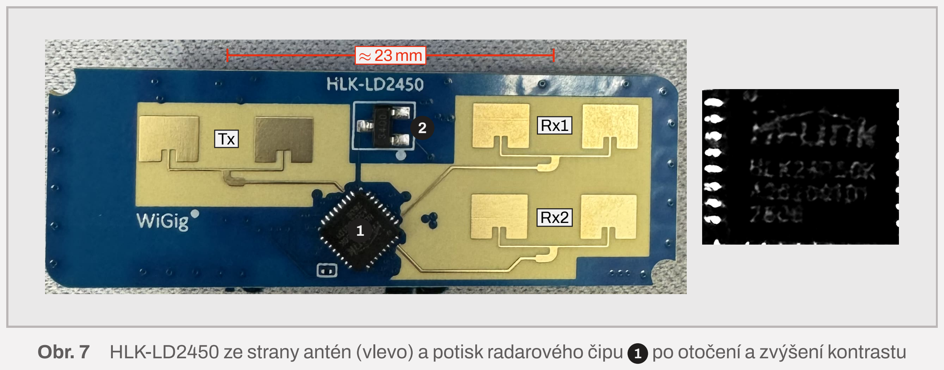
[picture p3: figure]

Obr. 7 HLK-LD2450 ze strany antén (vlevo) a potisk radarového čipu 1 po otočení a zvýšení kontrastu (vpravo). Vysílač Tx tvoří dvě plošky; přijímače Rx1 a Rx2 po dvou ploškách leží 6,4 mm nad sebou. Středy Tx a Rx1 dělí asi 23 mm.

Na obr. 7 je vidět uspořádání 1T2R, které uvádí výrobce. Antény jsou plošky (patch): obdélníky mědi nad zemní vrstvou desky, které rezonují na délce kolem půl vlnové délky v laminátu. Vlevo je vysílač, dvě plošky 4,1 × 3,1 mm s roztečí 8,1 mm na jednom vedení. Vpravo jsou dva přijímače, každý ze dvou plošek 3,8 × 3,1 mm s roztečí 7,6 mm. Řady přijímačů leží 6,4 mm nad sebou, zhruba půl vlnové délky ve vzduchu: z rozdílu fází mezi nimi modul počítá úhel cíle napříč deskou. Plošky jsou napájené od kratší hrany, takže polarizace míří podél kratší strany desky.

Dvojice plošek dává svazek kolem 40◦ podél delší strany desky a kolem 90◦ napříč, se ziskem kolem 9 dBi. Jsou to odhady z geometrie, ne měření. Anténní pole je bez nepájivé masky. Krémová barva laminátu napovídá vysokofrekvenční laminát třídy RO4350B (εr ≈ 3,6) a délka plošky 3,1 mm tomu odpovídá. Na FR4 by ale vyšla jen o 0,2 mm kratší, což z fotky nerozlišíme.

Radarový čip 1 je QFN-32 4 × 4 mm pootočený o 45◦
, aby vedení k anténám byla co nejkratší. Pouzdro odpovídá databriefu S3KM111L. Potisk ale patří Hi-Linku: logo, označení začínající HLK24 a dva řádky kódu šarže, bez značky ICLegend. Že jde o S3KM111L, zůstává hypotéza; shoduje se pouzdro i 1T2R, rozhodne až zapojení vývodů. Vedle čipu je součástka SOT-23 2 s potiskem 3400, nejspíš tranzistor; její roli neznáme.

## 36 LD2450: STRANA SOUČÁSTEK

Druhý čip s Bluetooth, dva krystaly, napájení a servisní plošky s linkami USB.

MMWAVE RADAR STUDY | LD2450: STRANA SOUČÁSTEK

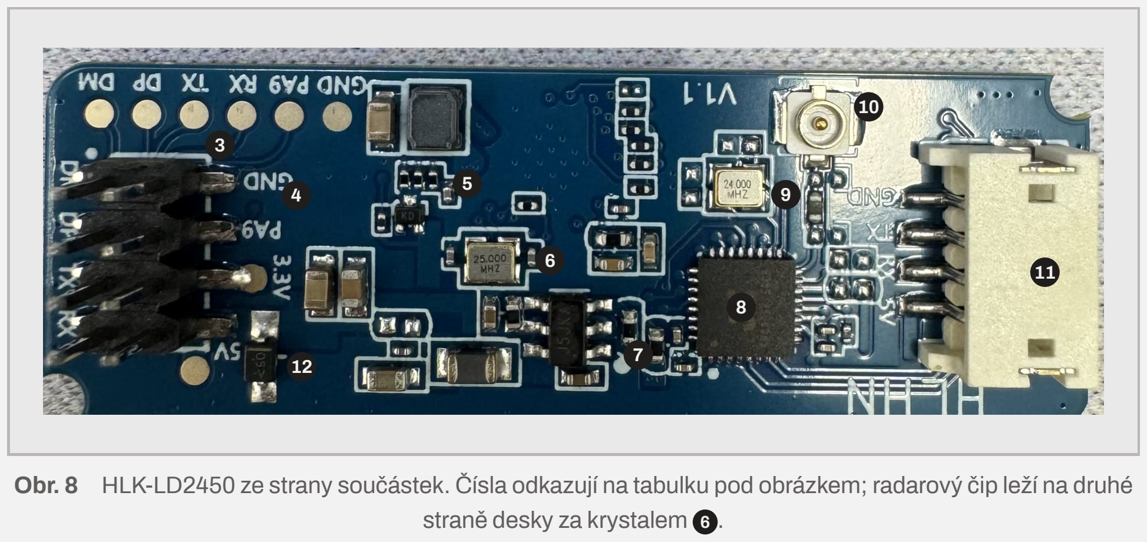
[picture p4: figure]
straně desky za krystalem 6 .

Obr. 8 HLK-LD2450 ze strany součástek. Čísla odkazují na tabulku pod obrázkem; radarový čip leží na druhé

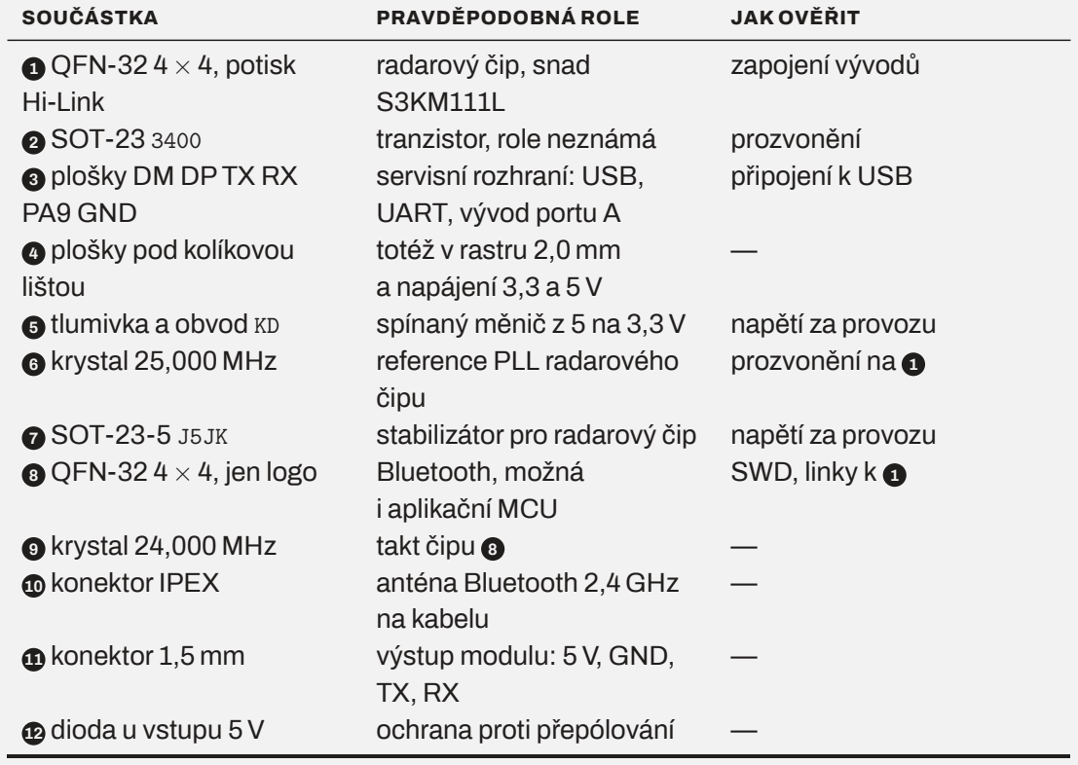
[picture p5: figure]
SOUČÁSTKA; PRAVDĚPODOBNÁ ROLE; JAK OVĚŘIT; 1 QFN-32 4 × 4, potisk; Hi-Link; radarový čip, snad; zapojení vývodů; 2 SOT-23 3400; tranzistor, role neznámá; prozvonění; 3 plošky DM DP TX RX; PA9 GND; servisní rozhraní: USB,; UART, vývod portu A; připojení k USB; 4 plošky pod kolíkovou; lištou; totéž v rastru 2,0 mm; a napájení 3,3 a 5 V; 6 krystal 25,000 MHz; reference PLL radarového; čipu; prozvonění na 1; 7 SOT-23-5 J5JK; stabilizátor pro radarový čip; napětí za provozu; i aplikační MCU; SWD, linky k 1; 9 krystal 24,000 MHz; takt čipu 8; 10 konektor IPEX; anténa Bluetooth 2,4 GHz; na kabelu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

5 tlumivka a obvod KD | spínaný měnič z 5 na 3,3 V | napětí za provozu
8 QFN-32 4 × 4, jen logo | Bluetooth, možná
12 dioda u vstupu 5 V | ochrana proti přepólování | —

Tabulka 12: Součástky LD2450 podle obr. 7 a 8. Role jsou hypotézy z fotek, poslední sloupec říká, čím je ověříme.

Na desce jsou dva čipy, které mohou nést firmware: radarový čip 1 a čip 8 s vlastním krystalem a ohebnou anténou Bluetooth na kabelu. Krystal 6 leží přímo za radarovým čipem a bude to jeho reference. Z fotek plynou dvě možná uspořádání:

MMWAVE RADAR STUDY | LD2451: DVĚ ŘADY PO OSMI PLOŠKÁCH

### 8 je aplikační mikrokontrolér s Bluetooth. Čte z radarového čipu vzorky přes rychlou

sběrnici, počítá cíle a posílá je konektorem 11. Inicializace čipu je pak ve firmwaru 8 a sběrnici mezi čipy jde odposlechnout.

Radarový čip je SoC s vlastním procesorem, který počítá cíle sám, a 8 je jen most do Bluetooth. Mezi čipy pak vede jen UART a inicializace je uvnitř 1 .

Každé uspořádání vede v etapě 3 dílu Praxe k jinému postupu. Rozhodne mezi nimi prozvonění: kolik linek spojuje 1 s 8 a kam vedou TX a RX konektoru 11.

Plošky 3 nesou kromě UART i linky DM a DP, tedy datové linky USB. Aspoň jeden čip má tedy USB, pravděpodobně kvůli nahrávání firmwaru. Označení PA9 je typické pro mikrokontroléry s porty pojmenovanými po vzoru STM32. Obojí je levná stopa: po připojení k počítači se ukáže, jestli se modul přihlásí jako zařízení USB, a identifikátor výrobce prozradí, čí čip ho obsluhuje.

## 37 LD2451: DVĚ ŘADYPO OSMI PLOŠKÁCH

Sériově napájené řady se svazkem kolem 15◦
v jedné rovině a na zadní straně samostatný mikrokontrolér s programovacími ploškami.

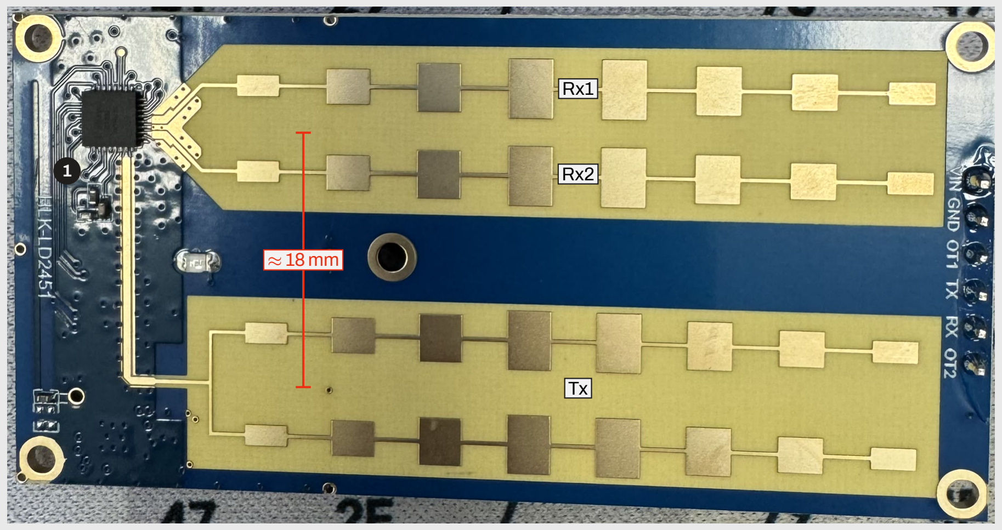
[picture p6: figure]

Obr. 9 HLK-LD2451 ze strany antén. Nahoře dva přijímače, každý jedna řada osmi plošek, dole vysílač ze dvou řad na jednom vedení. Středy vysílače a přijímačů dělí asi 18 mm; 1 je radarový čip.

LD2451 (obr. 9) má antény v sériově napájených řadách: osm plošek za sebou na jed-

MMWAVE RADAR STUDY | LD2451: DVĚ ŘADY PO OSMI PLOŠKÁCH

nom vedení. Plošky se k okrajům řady zmenšují, což potlačí postranní laloky. Horní dvě řady, 6,0 mm nad sebou, vedou každá do vlastního vývodu čipu. Dolní dvě, 7,8 mm od sebe, napájí jedno vedení s rozbočením. Uspořádání 1T2R proto nejspíš znamená dva přijímače nahoře a vysílač dole; dlouhé vedení k vysílači je obvyklá volba, protože ztráta v něm vadí méně než na příjmu.

Rozteč plošek je 6,6 mm a řada je dlouhá asi 53 mm, přes čtyři vlnové délky. Podél řady tak vychází svazek kolem 15◦

, napříč u vysílače kolem 40◦ a u přijímačů přes 80◦ . Zisk vysílací
antény odhadujeme na 15–16 dBi, tedy zhruba jako u navržené čočky; i to jsou odhady z geometrie. Radarový čip 1 je QFN-32 v rohu desky, jeho potisk z fotky nepřečteme.

Odtud plyne užitečná reference. Pokud LD2451 splňuje limit EIRP 20 dBm s anténou kolem 16 dBi, vysílá jeho čip nejvýš kolem 4 dBm — tedy přesně tolik, kolik smí vlastní deska s čočkou. Nastavení výkonu v jeho firmwaru proto ukáže, jak se tahle hodnota v čipu nastavuje.

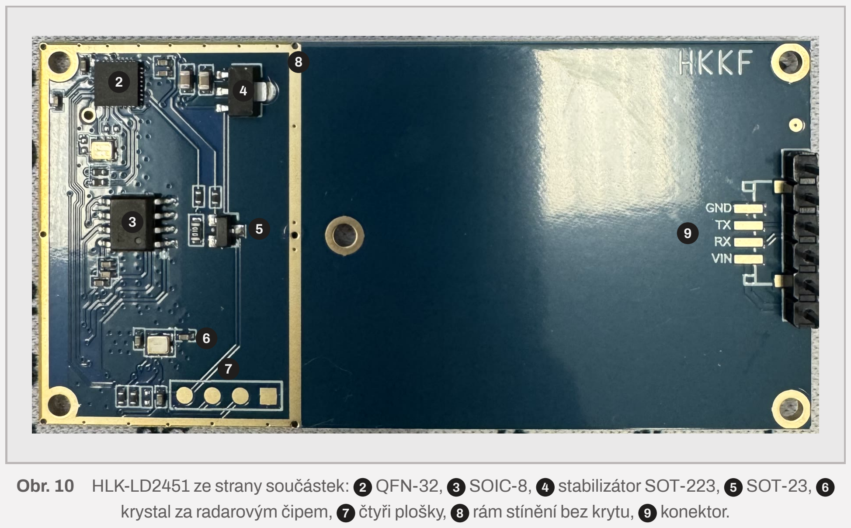
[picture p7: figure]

Obr. 10 HLK-LD2451 ze strany součástek: 2 QFN-32, 3 SOIC-8, 4 stabilizátor SOT-223, 5 SOT-23, 6 krystal za radarovým čipem, 7 čtyři plošky, 8 rám stínění bez krytu, 9 konektor.

Zadní strana (obr. 10) nese rám pro stínicí kryt 8 , kryt ale chybí. Uvnitř je QFN-32 2 , který vypadá jako běžný mikrokontrolér, SOIC-8 3 s nečitelným potiskem (paměť, nebo zesilovač), stabilizátor SOT-223 4 , součástka SOT-23 5 a krystal 6 přímo za radarovým čipem, obdoba krystalu 25 MHz u LD2450. Čtyři plošky 7 se čtvercovou ploškou jako vývodem 1 vypadají jako programovací rozhraní. Konektor 9 nese napájení, UART a dva spínací výstupy OT1 a OT2. USB tu nevidíme a anténu Bluetooth také ne, podle manuálu výrobce ale modul Bluetooth má (hlásí se jako LD2451_XXXX). Samostatný mikrokontrolér s programovacími ploškami z něj i tak dělá slibný cíl pro čtení firmwaru.

MMWAVE RADAR STUDY | CO Z TOHO PLYNE PRO ČOČKU

## 38 CO Z TOHO PLYNE PRO ČOČKU

Jedna čočka nad celým LD2450 nefunguje. Čočka jen nad přijímačem dá rozpočet výkonu cílového návrhu a nemění vyzářený výkon.

Kdyby osa čočky ležela uprostřed mezi vysílačem a přijímačem, byl by každý z nich 11,5 mm mimo ohnisko. Podle dílu Anténa a čočka se tím svazek vychýlí o úhel kolem d/f, tedy o 19–22◦
, každý na opačnou stranu. Dvoucestný diagram vznikne součinem obou svazků. U gaussovského svazku zůstane v ose, ztratí ale 2 · 12 (θ/θ3)

2 dB, tedy 18–25 dB, a aberace mimo osu ztrátu ještě zvětší. Drsnému povrchu na 5 m zbývá v rozpočtu výkonu 20 dB odstupu od šumu; po takové ztrátě nezbude nic.

Pro vývoj proto počítáme se třemi konfiguracemi (obr. 11):

A: bez čočky. Pro firmware, surová data a kalibraci. Svazek je široký, na drsné zdi by kolísání dosáhlo desítek centimetrů.

B: čočka jen nad přijímačem. Plná čočka ∅ 35 mm s osou nad Rx1, seříznutá 12 mm od osy, aby nezakrývala vysílač. Vysílač svítí bez čočky, takže vyzářený výkon zůstává jako u hotového modulu. Dvoucestný svazek určuje hlavně úzký svazek čočky.

C: dělená čočka. Dvě poloviny apertury, každá s osou nad svou anténou. V úzké rovině má svazek 23◦

jako návrh, v široké 46◦
. Vysílač získá kolem 4 dB, o které je nutné snížit výkon, pokud původní firmware vysílá blízko limitu.

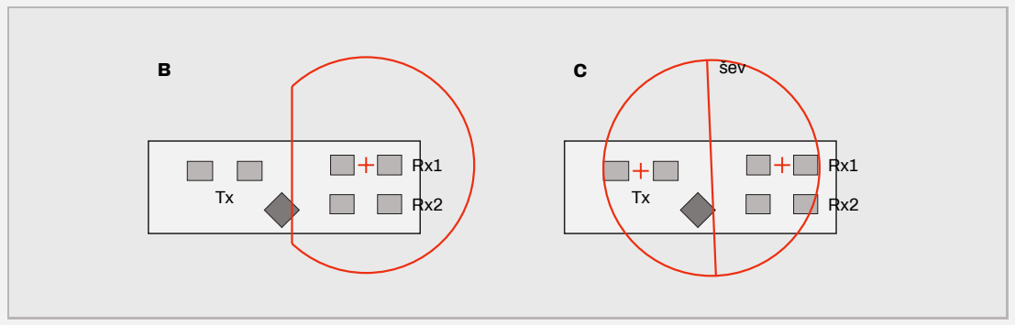
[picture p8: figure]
C šev

Obr. 11 Čočka nad LD2450 při pohledu shora, deska v měřítku. B: plná čočka ∅ 35 mm s osou nad Rx1,

seříznutá 12 mm od osy, aby nezakrývala vysílač. C: dělená čočka; každá polovina má osu nad svou anténou (křížky), šev leží uprostřed mezi nimi.

Svazky konfigurací nejsou kruhové a vysílač s přijímačem je nemají stejné. Model z dílu Odraz od plošného cíle se na to rozšíří dvěma kroky. V každé rovině se dvoucestný diagram spočte jako součin diagramů vysílače a přijímače. Posun i kolísání pak sečtou příspěvky obou rovin (vzorce v příloze Přehled vzorců). Z toho plyne ekvivalentní svazek v tabulce: kruhový svazek, který by dal stejný dvoucestný diagram, kdyby ho měl vysílač i přijímač.

MMWAVE RADAR STUDY | CO Z TOHO PLYNE PRO ČOČKU
KONFIGURACE | EKV. SVAZEK | Gt + Gr | KOLÍSÁNÍ | VYZÁŘENÝ VÝKON
A: bez čočky | 41 × 90◦ | 18 dB | 86 cm | beze změny
B: čočka nad Rx1 | 27 × 30◦ | 25 dB | 23–25 cm | beze změny
C: dělená čočka | 23 × 46◦ | 26 dB | 27 / 40 cm | +4 dB
cílový návrh | 22 × 22◦ | 32 − 7 dB | 17 cm | vysílač ≤ 4 dBm

Tabulka 13: Konfigurace LD2450 pro vývoj proti cílovému návrhu. Zisky jsou odhady z geometrie, kolísání jednoho měření na drsné zdi ve 5 m při náklonu 15◦ plyne z modelu. U C platí první číslo pro náklon v úzké rovině svazku.

Konfigurace B vychází nejblíž cíli. Rozpočet výkonu má stejný: cílová deska ztratí 7 dB ve vazebníku, B stejných 7 dB tím, že vysílač nemá čočku. Svazek je o čtvrtinu až o třetinu širší a model proto předpovídá kolísání asi 1,4krát větší než u cíle. Konfigurace C se hodí na jiný test: otočením modulu o 90◦ se náklon přesune z úzké roviny svazku do široké a model předpovídá, že kolísání vzroste asi 1,5krát. Obě varianty čočky vytvoří model
hw/lens/lens_24ghz.scad s parametrem cut, nebo sep.

Flag-checkered CO Z TOHO PLYNE

Fotky potvrdily 1T2R a pouzdro QFN-32 4 × 4 mm, typ čipu ale ne: LD2450 nese potisk Hi-Link. Vývoj s čočkou poběží v konfiguraci B, s čočkou jen nad přijímačem: rozpočet výkonu jako cílový návrh, ekvivalentní svazek 27–30◦ a vyzářený výkon beze změny. LD2451 s vysílací anténou kolem 16 dBi je reference pro nastavení výkonu a jeho samostatný mikrokontrolér slibný cíl pro čtení firmwaru.

MMWAVE RADAR STUDY | PLÁN A BRÁNY
Praxe | POSTUP

# Od modulu k prototypu

BOLT NA JEDEN POHLED

Osm etap vede od oživení hotových modulů po změřenou přesnost na zdi a rozhodnutí o vlastní desce. Každá má výstup a kritérium; dvě brány rozhodují, jestli se pokračuje. Pořadí určují závislosti: bez surových dat nejde změřit čočku a bez změřeného svazku nejde ověřit speckle. Výsledky patří do měřicího protokolu v příloze.

## 40 PLÁN A BRÁNY

Tři skupiny etap, mezi nimi dvě rozhodnutí. Tabulka říká, co má po každé etapě existovat.

Tok práce ukazuje obr. 12. Brána 1 po etapě 3 se ptá, jestli čip běží s naší rampou. Když ne, zbývá dokumentace pod NDA od výrobce, nebo záložní varianta s BGT24MTR11 a veřejnou dokumentací (díl Návrh). Brána 2 po etapách 4–7 se ptá, jestli měření sedí s modelem a čočka s výpočtem. Teprve pak má smysl kreslit vlastní desku.

ETAPA | VÝSTUP | HOTOVO, KDYŽ
1 oživení | záznam původního výstupu
| obou modulů | oba stabilně hlásí odražeč
2 mapování desky | schéma, role čipů, vývody | víme, kudy k firmwaru
3 firmware čipu | inicializace, vlastní firmware | čip běží s naší rampou
4 surová data | spektra, kalibrace, SNR | zbytky pod 1 cm, SNR do
| | ± 6 dB
5 čočka a svazek | index lomu, výška, diagram | svazek do ± 20 %, zisk do
| | ± 3 dB
6 přesnost | posun a kolísání na čtyřech
| cílech | model do ± 30 %
7 pohyb a časování | rozdíl ramp, frekvence,
| latence | rozdíl ∝ vT do ± 10 %,
| | ≥ 4 kHz
8 vlastní deska | rozhodnutí, podklady | obě brány prošly

Tabulka 14: Etapy. Výstup musí po etapě existovat; kritérium rozhoduje, jestli se pokračuje.

MMWAVE RADAR STUDY | PRACOVIŠTĚ A VYBAVENÍ

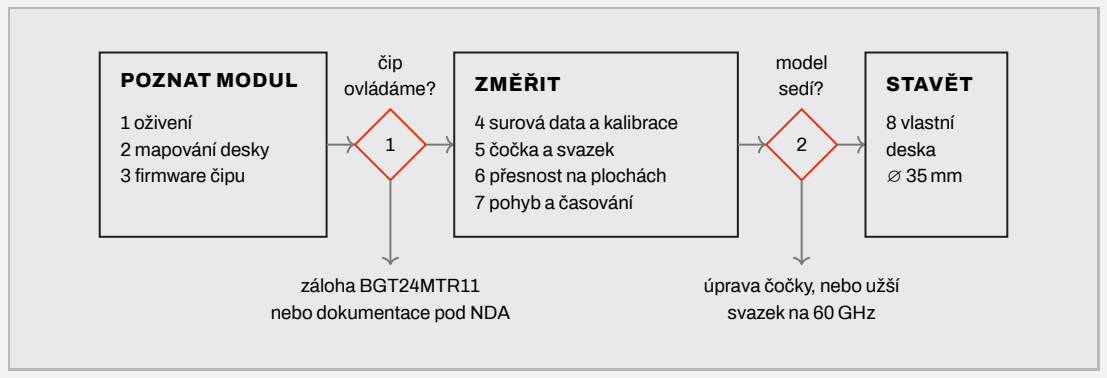
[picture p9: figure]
POZNAT MODUL; 1 oživení; 2 mapování desky; 3 firmware čipu; čip; ovládáme?; ZMĚŘIT; 4 surová data a kalibrace; 5 čočka a svazek; 6 přesnost na plochách; 7 pohyb a časování; model; sedí?; STAVĚT; 8 vlastní; deska; záloha BGT24MTR11; nebo dokumentace pod NDA; úprava čočky, nebo užší; svazek na 60 GHz

Obr. 12 Etapy praktické části. Vodorovně se pokračuje, když brána projde; dolů vede náhradní cesta. Etapy 5–7 lze po etapě 4 dělat souběžně.

## 41 PRACOVIŠTĚ A VYBAVENÍ

Stačí levné nástroje na ladění elektroniky a pár cílů z železářství. Jediná věc na 24 GHz, kterou sami neověříme, je absolutní kmitočet vysílání.

POLOŽKA | POČET | K ČEMU
HLK-LD2450 | 3 | reference, pokusy, dárce čipu
HLK-LD2451 | 1 | reference úzkého svazku a výkonu
zdroj 5 V s omezením proudu, bočník 1 Ω | 1 | napájení, časování z odběru
převodník USB–UART do 1 Mbd | 1 | výstup modulů
sonda SWD (ST-Link, Raspberry Pi Pico) | 1 | jádro, čtení a zápis firmwaru
logický analyzátor 24 MSa/s | 1 | UART, sběrnice při startu
rychlý analyzátor od 100 MSa/s | 1 | sběrnice se vzorky, je-li
mikroskop nebo makroobjektiv | 1 | potisky čipů
horkovzdušná stanice | 1 | přenos čipu v etapě 8
laserový dálkoměr | 1 | referenční vzdálenost
koutový odražeč, hrana 10 cm | 2 | bodový cíl
plech 1 × 1 m, překližka 18 mm | po 1 | hladké cíle
lineární vedení 1,5 m s vozíkem | 1 | přiblížení ke zdi
otočný stolek, dva stativy | 1 | diagram svazku
3D tiskárna, PETG | 1 | čočky, držáky, destičky

Tabulka 15: Vybavení. Moduly jsou skladem v ČR, zbytek jsou běžné nástroje.

Moduly HLK-LD2415H, HW-MS03 a RCWL-0516 dál nepoužíváme: jsou to dopplerovské senzory

MMWAVE RADAR STUDY | ETAPA 1: OŽIVENÍ S PŮVODNÍM FIRMWAREM

s nemodulovanou vlnou, které měří jen pohyb, ne vzdálenost.

Cíle mají svoje podmínky. Koutový odražeč ze tří navzájem kolmých trojúhelníkových desek vrací odraz zpět ke zdroji v širokém rozsahu úhlů. Chová se jako bodový cíl se známým radarovým průřezem σ = 4πa⁴/(3λ

2

), s hranou a = 10 cm 2,7 m² . Pro měření diagramu musí stát v dalekém poli, s touto hranou dál než asi 3,5 m; pro kalibraci vzdálenosti stačí blíž, protože odraz se vždy jeví z vrcholu odražeče. Hladkému plechu stačí několik Fresnelových zón: v 5 m má první zóna poloměr 18 cm, takže plech 1 × 1 m je pro zrcadlový odraz nekonečný. Drsná zeď naopak musí přesahovat celou stopu svazku, ve 5 m se svazkem konfigurace B kolem 2,7 m v průměru.

## 42 PRAVIDLA PRO VYSÍLÁNÍ PŘI VÝVOJI

Pásmo a limit vyzářeného výkonu platí i pro prototyp na stole.

Vysíláme jen v pásmu 24,00–24,25 GHz a s EIRP nejvýš 20 dBm (díl Anténa a čočka). V Česku je rámcem všeobecné oprávnění ČTÚ pro zařízení krátkého dosahu, jehož aktuální znění je třeba ověřit. Konfigurace A a B vysílač nemění, vyzářený výkon zůstává jako u hotového modulu. Konfigurace C přidá vysílači kolem 4 dB zisku a vlastní deska s čočkou 16 dBi smí vysílat nejvýš 4 dBm.

S vlastním firmwarem nastavujeme kmitočet rampy sami. Bez analyzátoru spektra změříme jen šířku přeladění, a to z kalibrace v etapě 4; polohu v pásmu ne. Proto přebíráme počáteční kmitočet z původního firmwaru a měníme jen délku a tvar rampy. Před delším provozem vlastního profilu jednou změříme spektrum zapůjčeným analyzátorem do 26,5 GHz s trychtýřovou anténou.

Hotový modul má shodu CE/RED pro původní firmware a anténu. Změnou profilu vysílání nebo přidáním čočky přechází odpovědnost za shodu na nás. Pro vývoj to nevadí, pro prodej ano.

## 43 ETAPA 1: OŽIVENÍ S PŮVODNÍM FIRMWAREM

Než modul otevřeme, zaznamenáme, co umí v původním stavu. Po každé úpravě pak víme, co jsme změnili.

1. Připojit LD2450 konektorem 11 (obr. 8) na zdroj 5 V s omezením proudu na 300 mA a na převodník USB–UART nastavený na 256 000 Bd, 8N1. Změřit odběr.
2. Zapisovat výstup do souboru s časovou značkou každého rámce. Podle dokumentace výrobce začíná rámec bajty AA FF 03 00, nese tři cíle (souřadnice x a y v mm, rychlost

MMWAVE RADAR STUDY | ETAPA 2: MAPOVÁNÍ DESKY

v cm/s) a končí 55 CC; formát ověříme na záznamu.

3. Postavit koutový odražeč na stativ do 2 a 4 m, ve stejné výšce jako senzor, a zaznamenat po 60 s. Z časových značek určit frekvenci výstupu, z hodnot rozptyl a odchylku od laserového dálkoměru.
4. Zapojit do přívodu 5 V bočník 1 Ω a zaznamenat průběh odběru (viz tip).
5. V aplikaci výrobce přes Bluetooth zapsat verzi firmwaru a všechna nastavení.
6. Totéž udělat s LD2451 podle jeho dokumentace.

Výstup: záznamy obou modulů a tabulka frekvence výstupu, rozptylu a odchylky. Hotovo, když oba moduly stabilně hlásí odražeč na správné vzdálenosti.

LIGHTBULB ČASOVÁNÍ RAMPY Z ODBĚRU

Vysílač a přijímač se zapínají po rámcích chirpů a každý rámec je vidět jako proudový pulz. Bočník 1 Ω v přívodu a osciloskop nebo analogový vstup analyzátoru tak ukážou periodu i délku rámců ještě před prvním řádkem vlastního kódu.

## 44 ETAPA 2: MAPOVÁNÍ DESKY

Z hypotéz dílu Rozbor uděláme zapojení: který čip nese firmware, jak se k němu připojit a kudy teče komunikace mezi čipy.

1. Nafotit všechny čipy obou modulů makroobjektivem nebo mikroskopem se světlem dopadajícím pod malým úhlem a přečíst potisky.
2. Na modulu bez napájení prozvonit linky TX a RX konektoru 11 (na který čip vedou), krystal 6 (na které vývody 1 ) a plošky 3 a 4 .
3. Spočítat linky mezi 1 a 8 . Dvě znamenají UART, čtyři a víc sběrnici SPI nebo podobnou. Tím se rozhodne mezi hypotézami z dílu Rozbor.
4. Za provozu změřit napětí za měničem 5 a stabilizátorem 7 .
5. Připojit plošky DM, DP, 5 V a GND na kabel USB a sledovat, jestli se modul přihlásí jako zařízení USB. Zopakovat s PA9 připojeným přes 10 kΩ na zem a pak na 3,3 V, protože zavaděče často čtou úroveň vývodu po resetu. Identifikátor výrobce USB prozradí výrobce čipu.
6. Na LD2451 najít u plošek 7 (obr. 10) zem a napájení; zbylé dvě jsou kandidáti na datovou a hodinovou linku SWD.
7. Zapojení obou modulů zakreslit do schématu.

MMWAVE RADAR STUDY | ETAPA 3: FIRMWARE A INICIALIZACE ČIPU

Výstup: schéma, role obou čipů a seznam vývodů radarového čipu (vysokofrekvenční, napájení, krystal, rozhraní). Hotovo, když víme, který čip nese firmware a jak se k němu připojit.

## 45 ETAPA 3: FIRMWARE A INICIALIZACE ČIPU

Cílem je spustit čip s vlastní rampou. Cesta vede přes přečtený firmware, nebo přes odposlech sběrnice mezi čipy.

1. Připojit sonduSWD(dvouvodičové ladicí rozhraní procesorů ARM Cortex-M) k čipu s firmwarem a přečíst identifikaci ladicího portu. Ta určí jádro procesoru i bez čitelného potisku.
2. Zkusit přečíst celou paměť flash. Brání-li tomu ochrana čtení, nic nemazat (viz varování) a pokračovat krokem 4.
3. Ve firmwaru najít tabulku zápisů do registrů radarového čipu, obvykle dvojice adresa– hodnota posílané po startu.
4. Nejde-li firmware přečíst a mezi čipy vede sběrnice, zaznamenat analyzátorem start modulu. Pak přes příkazy výrobce změnit jedno nastavení (dosah, citlivost) a záznam zopakovat. Rozdíl dvou záznamů ukáže, které registry nesou které nastavení; tomu se říká diferenciální záznam.
5. Z registrů rampy určit šířku přeladění, délku chirpu a počet vzorků původního firmwaru. Vyjde-li přeladění širší než 250 MHz, modul v EU nesmí vysílat ani v původním stavu.
6. Nahrát vlastní firmware s původní inicializací a ověřit, že výstup sedí s etapou 1. Teprve pak měnit rampu: trojúhelníková, uvnitř 24,00–24,25 GHz, s nejkratším chirpem, který čip přijme.

Výstup: inicializační sekvence, popis registrů rampy, vlastní firmware. Hotovo, když čip běží s naší trojúhelníkovou rampou (brána 1).

Exclamation-Triangle ODEMČENÍ OCHRANY ČTENÍ SMAŽE FIRMWARE

U většiny mikrokontrolérů se ochrana čtení zruší jen smazáním celé paměti, i s inicializací radarového čipu, kterou hledáme. Krok je nevratný. Dělá se jen na modulu určeném k pokusům a až poté, co máme záznam sběrnice nebo přečtený firmware z jiného kusu. Jeden modul zůstává vždy nedotčený jako reference.

MMWAVE RADAR STUDY | ETAPA 5: ČOČKA A SVAZEK

## 46 ETAPA 4: SUROVÁ DATA A KALIBRACE VZDÁLENOSTI

První spektrum v počítači a převod kmitočtu na vzdálenost změřený, ne spočítaný.

1. Posílat do počítače surové vzorky I/Q obou přijímačů z vybraných chirpů, z vlastního firmwaru přes UART nebo USB.
2. Zpracovat je stejně jako simulace v sim/: Hannovo okno, FFT, parabolická interpolace vrcholu.
3. Koutový odražeč postupně postavit do 1, 2, 3, 4 a 5 m, s laserovým dálkoměrem jako referencí, a naměřené vzdálenosti proložit přímkou. Sklon ukáže chybu poměru B/T, posun polohu fázového středu a zpoždění v čipu.
4. Změřit SNR vrcholu odražeče proti šumu okolních buněk a porovnat ho s předpovědí (příklad). Rozdíl dá jedno číslo za dvě neznámé: vysílací výkon minus šumové číslo.
5. Zaznamenat prázdnou scénu bez odražeče. Co v jeho buňce zbude, je odraz okolí; odražeč ho má převyšovat aspoň o 20 dB.
6. Změřit vazbu vysílače do přijímače jako vrchol u nulového kmitočtu a z histogramu vzorků ověřit, že převodník neořezává.

Výstup: kalibrační konstanty, SNR a úroveň vazby. Hotovo, když zbytky po kalibraci jsou od 1 do 5 m pod 1 cm a SNR je do ± 6 dB od předpovědi.

TERMINAL SNR KOUTOVÉHO ODRAŽEČE

LD2450 bez čočky (zisky 2 × 9 dBi), vysílač 4 dBm, odražeč s hranou 10 cm (σ = 2,7 m²

) ve 2 m: radarová rovnice pro bodový cíl dá Pr ≈ −57 dBm. Šum na buňku je pro chirp 10 µs a šumové číslo 15 dB −107 dBm, takže SNR vychází kolem 50 dB. Při chirpu 100 µs klesne šum o 10 dB a SNR stoupne na 60 dB.

## 47 ETAPA 5: ČOČKA A SVAZEK

Čočka se ladí měřením: index lomu, výška nad anténou, diagram a trubka proti přesahu.

1. Vytisknout destičku 60 × 60 × 10 mm se stejným nastavením jako čočku (PETG, 100 % výplň) a změřit index lomu (příklad).
2. Přepočítat model s naměřeným n a vytisknout čočku pro konfiguraci B (-D cut=12), případně C (-D sep=23).

MMWAVE RADAR STUDY | ETAPA 6: PŘESNOST NA PLOŠNÝCH CÍLECH
3. Čočku uložit do držáku s podložkami po 0,5 mm. Odražeč postavit do osy ve 3,5 m, výšku čočky měnit v rozsahu ± 3 mm kolem výpočtu a ponechat tu s nejvyšším SNR.
4. Senzor postavit na otočný stolek, odražeč do 3,5 m nebo dál, a změřit amplitudu vrcholu v rozsahu ± 40◦ po 2◦ v obou rovinách, v konfiguraci A i B. Diagram B dělený odmocninou diagramu A dá jednocestný diagram čočky, protože holý vysílač a holý přijímač mají podobné svazky.
5. Mezi modul a čočku postupně vložit trubku bez výstelky, s hliníkovou páskou a s vodivou pěnou z antistatického obalu. Porovnat vazbu u nulového kmitočtu a boční laloky diagramu.

Výstup:index lomu, optimální výška, diagram a volba trubky. Hotovo, když šířka svazku sedí s výpočtem do ± 20 % a zisk přijímače vzroste proti holému Rx o 7 ± 3 dB.

TERMINAL INDEX LOMU ZMĚŘÍ RADAR SÁM

Plech stojí ve 2 m, do svazku se vloží destička tloušťky t = 10 mm. Zdánlivá vzdálenost se prodlouží o (n − 1)t; prodloužení 6,2 mm znamená n = 1,62. Při SNR 60 dB má rozdíl dvou měření rozptyl kolem 0,5 mm, tedy n na ± 0,05; průměry ze sta měření dají ± 0,005. Fáze vrcholu je ještě přesnější: prodloužení o 6,2 mm ji otočí právě o 2π, poloha vrcholu tedy rozhodne jen o počtu otáček.

## 48 ETAPA 6: PŘESNOST NA PLOŠNÝCH CÍLECH

Hlavní měření studie: posun a kolísání na hladkých a drsných plochách, kolmo a při náklonu.

lineární vedení 1,5 m

radar + laser

posuv po 1 cm, L = 1,2 m

zeď

α

R = 2 nebo 5 m

Obr. 13 Sestava pro etapu 6 při pohledu shora, bez měřítka. Senzor a laserový dálkoměr jedou na vozíku po vedení ke zdi, zeď je nakloněná o α proti kolmici k vedení. Červeně stopa svazku.

MMWAVE RADAR STUDY | ETAPA 7: POHYB, DOPPLER A ČASOVÁNÍ
1. Připravit cíle: plech 1 × 1 m, překližku 18 mm, hladkou omítnutou zeď a neomítnutou cihlovou zeď.
2. Senzor v konfiguraci B a laserový dálkoměr upevnit na vozík lineárního vedení ve výšce aspoň 1,2 m (obr. 13). Svazek nesmí mířit na podlahu ani stěny v dosahu cíle; ve 2 m to v běžné místnosti jde, ve 5 m je potřeba velká hala nebo venkovní zeď.
3. V klidu udělat tisíc měření v jedné poloze. Jejich rozptyl je šum, který má při změřeném SNR vyjít kolem 0,6 ∆R/

√
SNR (díl Teorie: signál).
4. Pak vozík posouvat po 1 cm přes 1,2 m a v každé ze 120 poloh zprůměrovat deset měření. Statistika přes polohy dá posun b, kolísání sR jednoho měření a chybu průměru přes celou dráhu. Jízdu opakovat pětkrát s vedením posunutým pokaždé o 20 cm do strany: jedna jízda dává ve 5 m jen asi osm nezávislých realizací speckle.
5. Měřit kolmo a s vedením natočeným o 15◦ proti kolmici ke zdi, ve 2 a 5 m. U konfigurace C navíc s modulem otočeným o 90◦
6. Výsledky porovnat s předpovědí pro použitou konfiguraci (příloha Měřicí protokol).

Výstup: tabulka posunu, kolísání a chyby průměru pro každý cíl a náklon. Hotovo, když kolísání i chyba průměru sedí s modelem do ± 30 % (brána 2). Pak lze čísla z dílu Návrh použít pro vlastní desku.

Times TISÍC MĚŘENÍ Z JEDNOHO MÍSTA SPECKLE NEZMĚŘÍ

V klidu je speckle zamrzlý. Tisíc měření z jedné polohy dá malý rozptyl a k němu pevnou chybu, která s kolísáním z modelu nesouvisí. Proto se přibližuje po centimetrech: speckle se mění s dráhou, ne s časem, a pomalý posun přes 1,2 m nahradí 5 ms přiblížení při 240 m/s.

## 49 ETAPA 7: POHYB, DOPPLER A ČASOVÁNÍ

Rychlost 240 m/s v laboratoři nevyrobíme. Dopplerův posuv odhadu ale závisí jen na součinu vT, takže delší chirp a pomalý cíl dají stejný efekt.

Posun odhadu ∆RD = vcT/(λB)je při 240 m/s a chirpu 10 µs stejný jako při 24 m/s a 100 µs. Pro plech tažený rychlostí 2 m/s a chirp 100 µs předpovídá model rozdíl mezi klesající a stoupající rampou 2∆RD = 3,9 cm. Na plechu s SNR přes 50 dB je šum jednoho měření kolem milimetru, takže rozdíl je dobře měřitelný.

1. Nastavit trojúhelníkovou rampu s dlouhým chirpem, 100 µs, pokud ho čip přijme.
2. Plech 0,5 × 0,5 m na vozíku vedení táhnout k senzoru rychlostí 1–3 m/s. Rychlost určit z toho, jak se s časem mění průměr obou ramp.

MMWAVE RADAR STUDY | ETAPA 8: ROZHODNUTÍ O VLASTNÍ DESCE
3. Porovnat rozdíl R↓ − R↑ s předpovědí 2vcT/(λB) a ověřit, že průměr ramp sleduje trajektorii bez posunu.
4. Zopakovat s chirpem 10 µs: rozdíl musí klesnout desetkrát.
5. Vlastní firmware přepne vývod na začátku každé dvojice chirpů a po odeslání výsledku. Analyzátor z toho změří frekvenci měření, latenci a její rozptyl.

Výstup:rozdíl ramp proti vT, frekvence měření a latence. Hotovo, když rozdíl ramp odpovídá vT do ± 10 %, frekvence měření je aspoň 4 kHz a rozptyl latence je pod 50 µs. Stálou latenci jde vykompenzovat výpočtem, její rozptyl ne: 50 µs při 240 m/s znamená 1,2 cm. Zkouška při skutečné rychlosti patří až na cílovou aplikaci.

## 50 ETAPA 8: ROZHODNUTÍ O VLASTNÍ DESCE

Vlastní deska ∅ 35 mm má smysl, až když projdou obě brány.

1. Zkontrolovat podmínky: čip běží s vlastní rampou (etapa 3), čočka sedí s výpočtem (etapa 5), model speckle sedí s měřením (etapa 6).
2. Navrhnout desku podle zapojení z etapy 2: radarový čip s krystalem a stabilizátorem, vazebník rat-race, jednu anténu pod čočkou a mikrokontrolér, pokud radarový čip nemá vlastní procesor.
3. Pro první kusy přenést radarový čip z modulů LD2450 horkým vzduchem, dokud nemáme nabídku od výrobce. Je-li čip SoC s vlastní pamětí, přenese se s ním i jeho firmware.
4. Na vlastní desce zopakovat etapy 4–7. Teprve tato čísla nahradí výpočty v dílu Návrh.

Neprojde-li brána 2 kvůli čočce, pomůže úprava výšky nebo trubky. Rozchází-li se model s měřením na drsných plochách, je na místě přehodnotit svazek: 10◦ se do ∅ 35 mm vejde jen na 60 GHz (díl Návrh).

Flag-checkered CO Z TOHO PLYNE

Praktická část stojí na dvou rozhodnutích: jestli ovládneme čip (etapa 3) a jestli model speckle sedí s měřením na skutečné zdi (etapa 6). Ostatní etapy k nim vedou. Vývojová platforma je LD2450 s čočkou jen nad přijímačem; každé měření se zapisuje do protokolu v příloze vedle předpovědi, kterou ověřuje.

MMWAVE RADAR STUDY | MĚŘICÍ PROTOKOL
PŘÍLOHA | REFERENCE

# Měřicí protokol

Každý řádek páruje veličinu, kterou změří díl Praxe, s předpovědí ze studie. Číslo na začátku řádku je etapa. Sloupec Naměřeno se vyplní během etap a podle něj se aktualizuje díl Návrh. Předpovědi pro drsné plochy platí pro konfiguraci B, případně C, a pro model z dílu Odraz od plošného cíle rozšířený na eliptický svazek.

VELIČINA | PŘEDPOVĚĎ | NAMĚŘENO

### 1 frekvence výstupu, původní firmware

LD2450

10 Hz (výrobce)

2 rozestup středů Tx a Rx1, LD2450 | 23 mm (z fotky)
2–3 jádro a paměť čipu s firmwarem | —
3 šířka přeladění, původní firmware | ≤ 250 MHz
3 nejkratší chirp, který čip přijme | cíl 10 µs
4 zbytky kalibrace vzdálenosti 1–5 m | < 1 cm

### 4 SNR odražeče 10 cm ve 2 m, A, chirp

10 µs

50 dB při 4 dBm
a F = 15 dB
4 vazba Tx–Rx proti vrcholu odražeče | —

Tabulka 16: Modul, čip a signál.

MMWAVE RADAR STUDY | MĚŘICÍ PROTOKOL
VELIČINA | PŘEDPOVĚĎ | NAMĚŘENO
5 index lomu PETG, 100 % výplň | ≈ 1,62
5 výška rovné plochy nad anténou | 36 mm (C: 38 mm)
5 šířka svazku čočky | 21–23◦
5 přírůstek zisku proti holému Rx | +7 dB

### 6 šum v klidu proti 0,6 ∆R/

√
SNR | poměr 1,0
6 posun b, cihla, B, kolmo, 2 / 5 m | 4,6 / 11 cm
6 kolísání sR, cihla, B, 2 m | 4,6 / 9–10 cm
6 kolísání sR, cihla, B, 5 m | 11 / 23–25 cm
6 chyba průměru přes 1,2 m, cihla, B, 5 m | 3,8 / 5,5 cm

### 6 kolísání sR, cihla, C, 2 m, 15◦ v úzké /

široké rovině

11 / 16 cm

6 posun překližky 18 mm proti plechu | ≈ 1 cm
7 rozdíl ramp, 2 m/s, chirp 100 µs | 3,9 cm
7 frekvence měření, vlastní firmware | ≥ 4 kHz
7 rozptyl latence | < 50 µs

Tabulka 17: Čočka, přesnost a pohyb. Dvě čísla oddělená lomítkem platí pro kolmou zeď a náklon 15◦ , není-li
řečeno jinak.

MMWAVE RADAR STUDY | PŘEHLED VZORCŮ
PŘÍLOHA | REFERENCE

# Přehled vzorců

Vztahy z teoretických dílů, z návrhu a z rozboru modulů na jednom místě. c je rychlost světla, λ vlnová délka, B šířka přeladění, T délka chirpu, R vzdálenost.

VELIČINA | VZTAH
rozdílová frekvence | fb = 2RB/(cT)
rozlišení | ∆R = c/2B
Cramér–Raova mez | σR ≥ 0,39 ∆R/

√
| SNR; prakticky 0,6 ∆R/

√
SNR
parabolická interpolace | δ = 1/2(α − γ)/(α − 2β + γ)
dopplerovský posuv | fd = 2v/λ
Dopplerův posuv odhadu | ∆RD = vcT/(λB)
kombinace ramp | R = (R↑ + R↓)/2, v = λB(R↓ − R↑)/(2cT)
šum na buňku | NdBm = −174 + 10 log10(1,5/T) + FdB
bodový cíl | Pr = PtG²λ 2σ/((4π) 3R⁴ )
zrcadlová plocha | Pr = PtG²λ
| 2 |Γ| 2/((4π)
| 2 (2R)
| 2 )
drsná plocha | σ = σ 0R² πθ²
| 3 /(8 ln 2), Pr ∝ G/R²
činitel odrazu kolmo | Γ = (1 −

√

| εr)/(1 + √ εr)
Rayleighovo kritérium | ρ = exp[−(4πh cos θi/λ)
| 2 ]
první Fresnelova zóna | r1 =

p
| λR/2
posun od stopy svazku | b = Rθ²
| 3 (1 + tan² α)/(16 ln 2)
kolísání (speckle) | sR ≈ Rσθ

q
| σ
| 2

θ + tan² α, σθ = θ3/

√
16 ln 2
průměr přes dráhu L | σprům ≈

p
sRλR/(4L)
šířka svazku | θ3 ≈ (58 až 70) λ/D [

◦
]
zisk apertury | G ≈ η(πD/λ)

2
daleké pole | Rff = 2D²/λ
profil čočky | r

2 = 2(n − 1)fz + (n

2 − 1)z

2
odraz na ploše čočky | |Γ|

2 = ((n − 1)/(n + 1))²
protiodrazná vrstva | nm =

√
n, tloušťka λ0/(4nm)
EIRP | Pt + G ≤ 20 dBm (24,00–24,25 GHz)
vychýlení svazku
zdrojem mimo osu

θ ≈ d/f; dva svazky vychýlené na opačné strany ztratí dvoucestně ≈ 24 (θ/θ3)

2 dB
dvoucestný svazek dvou
různých antén

v každé rovině σ

2
θ = 1/[8 ln 2 (θ

−2
t + θ

−2
r

)]; ekvivalentní svazek

θ3 = σθ

√
16 ln 2
posun a kolísání, eliptický svazek

náklon v rovině x: b = R [σ

2
x

(

1

2 + tan² α) + 1
2

σ

2
y

],
s

2

R = R²
[σ

2
x

tan² α + 2σ
4
x

(

1
2 + tan² α)
2 +
1/2 σ

4
y

]

MMWAVE RADAR STUDY | PŘEHLED VZORCŮ
VELIČINA | VZTAH
koutový odražeč | σ = 4πa⁴/(3λ

2
), a je délka hrany

MMWAVE RADAR STUDY | ZVAŽOVANÉ A ZAMÍTNUTÉ VARIANTY
PŘÍLOHA | REFERENCE

# Zvažované a zamítnuté varianty

Během studie jsme prošli řadu cest. Tabulka shrnuje, proč nevyhrály, aby se k nim nebylo třeba vracet.

VARIANTA | PROČ NEVYHRÁLA
Parkside PLEM 20 A4 | fázový měřák s uzavřeným ASICem, frekvence i integrace zadrátované v čipu
optický dToF (LightWare SF30/D) | zadání splní, cenou patří mezi měřicí techniku
levné dToF senzory (VL53Lxx, TMF8828, TF-Luna) | desítky až stovky Hz, vícezónové čipy navíc integrují desítky ms

hotové radarové moduly
(NanoRadar NRA24,
MR72)

neznámé chování firmwaru při 240 m/s, cena a velikost

vyřazené automobilové
radary (ARS408, ESR)

77 GHz, filtry věrohodnosti ve firmwaru, velikost

24 GHz s polem 8×8 | velikost 130×70 mm, do ∅ 35 se nevejde
diskrétní front-end na 60/77 GHz | jednotlivé obvody stojí desítky eur, vyžadují speciální laminát
| a bez měřicí techniky do 80 GHz je nelze ověřit
60 GHz s anténou v pouzdře (IWRL6432AOP) | technicky vhodný i pro 30 m s čočkou ∅ 35, cenu se nepodařilo
| zjistit
Acconeer A121 | nejmenší varianta, ale zhruba 3× dražší; chování při 240 m/s
| neověřené, protože vzdálenostní body snímá postupně
radar se stojatým vlněním | stejné meze jako FMCW; výhodou je jediná anténa, nevýhodou
| malý signál na velké stejnosměrné složce a vícenásobné
| odrazy
FSK (několik diskrétních tónů) | milimetrová přesnost pro jeden cíl, ale měří jen za pohybu
UWB čipy jako radar (DW3000) | velké antény a široký svazek na 6,5–8 GHz
využít 1 GHz modulace S3KM111L | mimo pásmo 24,00–24,25 GHz je vysílání v EU nelegální

MMWAVE RADAR STUDY | ZVAŽOVANÉ A ZAMÍTNUTÉ VARIANTY
VARIANTA | PROČ NEVYHRÁLA

jedna čočka nad celým
LD2450

vysílač a přijímač jsou 23 mm od sebe; svazky se vychýlí o 19–22◦ a dvoucestně ztratí 18–25 dB

MMWAVE RADAR STUDY | ZDROJE A VSTUPNÍ DATA
PŘÍLOHA | REFERENCE

# Zdroje a vstupní data

### 54.1 Co nebylo ověřeno

Dokument stojí na katalogových údajích výrobců, veřejné dokumentaci, výpočtech a simulacích. Nic z uvedených dosahů, přesností, šířek svazku ani cen nebylo ověřeno vlastním měřením ani poptávkou. Konkrétně chybí:

parametry čipu S3KM111L — minimální délka chirpu, šířka pásma IF, vysílací výkon, šumové číslo, kompresní bod přijímače, cena a dostupnost dokumentace,

koeficienty zpětného rozptylu σ

0
, drsnosti a permitivity povrchů na 24 GHz (orientační hodnoty),

index lomu a ztrátový činitel tištěných plastů, poloha fázových středů antén LD2450,

model speckle je ověřený jen simulací, ne měřením na skutečné zdi; jeho rozšíření na eliptický svazek jen výpočtem, ani simulací,

identita radarových čipů LD2450 (potisk Hi-Link) a LD2451 (potisk nečitelný) a role druhého čipu na obou modulech,

rozměry antén modulů z fotografií (± 5 %) a z nich odhadnuté svazky a zisky,

chování A121 při rychlosti 240 m/s,

regulatorní rámec: limit EIRP podle ERC/REC 70-03 a harmonizované normy (ETSI EN 305 550 a související) v aktuálním znění.

### 54.2 Vstupní data a simulace

Fotodokumentace teardownu Parkside PLEM 20 A4 a modulů HLK-LD2450 a LD2451 je ve složce img/, výřezy pro sazbu v docs/fig/. Manuály výrobce obou modulů jsou v docs/datasheet/. Model čočky včetně dělené a seříznuté varianty je v hw/lens/. Simulace interpolace vrcholu a speckle na drsné zdi jsou ve složce sim/; jsou napsané v čistém Pythonu bez dalších knihoven.

MMWAVE RADAR STUDY | ZDROJE A VSTUPNÍ DATA

### 54.3 Zdroje

ZDROJ | CO Z NĚJ POCHÁZÍ
ICLegend, S3KM111L databrief (Sekorm) | integrovaný 24GHz čip: trojúhelníková rampa, až 8 kHz chirpů,
| QFN-32 4×4 mm
Hi-Link, manuály HLK-LD2450 a LD2451 v1.0 | parametry modulů: FMCW, 1T2R, rozměry, šířka svazku
| a přeladění, rozteče konektorů, zapojení vývodů, Bluetooth
| LD2451
Hi-Link, HLK-LD2415H | CW dopplerovský modul, důvod vyřazení
Hi-Link, sériový protokol LD2450 | rychlost 256 000 Bd, formát výstupního rámce (ověřit na
| záznamu)
vlastní fotografie,

## img/IMG_2152–2155

| rozměry antén, součástky a potisky modulů LD2450 a LD2451
Infineon, BGT24MTR11 | 24GHz transceiver pro záložní variantu, ceny RS
Acconeer, A121 | 60GHz pulzní koherentní radar, ceny LCSC a DigiKey
Infineon, BGT60TR13C | 60GHz čip s anténou v pouzdře, šířka pásma 5,5 GHz
TI, IWRL6432AOP | 60GHz FMCW s anténou v pouzdře, IF 5 MHz, ADC 12,5 MSPS
TI, AWR2944 a IWR6843 | šířka přeladění 4–4,5 GHz v pásmech 77 a 60 GHz
LightWare, SF30/D | optický dálkoměr 200 m, až 20 000 měření/s
Broadcom, AFBR-S50MV85G | optický dToF: 10 m, až 3000 snímků/s
nanoradar-protocols, tier4/ars408_driver (GitHub) | protokoly hotových a automobilových radarů
ERC/REC 70-03 | limit EIRP 100 mW pro 24,00–24,25 GHz (neověřené aktuální znění)

MMWAVE RADAR STUDY | SLOVNÍČEK POJMŮ
PŘÍLOHA | REFERENCE

# Slovníček pojmů

POJEM | VÝZNAM JEDNOU VĚTOU
FMCW | radar se spojitou vlnou, jejíž kmitočet lineárně přelaďujeme;
| vzdálenost vypadne z rozdílu kmitočtů
chirp | jedna kmitočtová rampa vysílaného signálu
trojúhelníková rampa | střídání stoupajícího a klesajícího chirpu; ruší Dopplerův posuv
| odhadu vzdálenosti
rozdílová frekvence | rozdíl mezi vyslaným a přijatým kmitočtem, přímo úměrný
| vzdálenosti cíle
I/Q vzorkování | vzorkování dvou kanálů posunutých o 90◦ ; dává komplexní
| signál se znaménkem kmitočtu
okno | váhová funkce vzorků před FFT, která potlačí postranní laloky
| spektra
parabolická interpolace | dopočet polohy vrcholu mezi body FFT z tří hodnot
rozlišení | nejmenší vzdálenost, na které radar oddělí dva cíle; c/2B
přesnost | jak přesně radar určí polohu jednoho cíle; omezuje ji odstup
| signálu od šumu
Cramér–Raova mez | teoretická nejmenší chyba odhadu při daném odstupu signálu
| od šumu
Dopplerův posuv | změna kmitočtu odrazu pohybujícího se cíle; u FMCW posune
| odhad vzdálenosti
šumové číslo | o kolik přijímač zhorší odstup signálu od šumu proti ideálnímu
blikavý šum (1/f) | šum směšovače, který roste k nízkým kmitočtům
plošný cíl | cíl, který vyplní celý svazek; přijatý výkon klesá s R²
zrcadlový odraz | koherentní odraz od hladké plochy, vzniká v první Fresnelově
| zóně
difúzní rozptyl | odraz od drsné plochy do všech směrů
první Fresnelova zóna | skvrna kolem paty kolmice, ze které vzniká zrcadlový odraz
Rayleighovo kritérium | mez drsnosti, nad kterou se plocha přestává chovat jako
| zrcadlo
koeficient zpětného rozptylu | σ
| 0 , radarový průřez drsné plochy na jednotku plochy
HPBW | šířka svazku v bodech polovičního výkonu
stopa svazku | část plochy ozářená svazkem

MMWAVE RADAR STUDY | SLOVNÍČEK POJMŮ
POJEM | VÝZNAM JEDNOU VĚTOU
posun od stopy svazku | systematický posun odhadu za kolmou vzdálenost u drsné
| plochy
speckle | náhodné kolísání odhadu kvůli sčítání příspěvků drsné plochy
| s náhodnými fázemi
hyperbolická čočka | čočka, jejíž plocha převede kulovou vlnu z ohniska na rovinnou
protiodrazná vrstva | vrstva tloušťky čtvrt vlny, která potlačí odraz na ploše čočky
přesah | část vyzářeného výkonu, která čočku mine
EIRP | ekvivalentní izotropně vyzářený výkon; součet vysílacího
| výkonu a zisku antény
dToF | přímé měření doby letu pulzu
fázový měřák | měření vzdálenosti z fázového posuvu modulovaného svazku
pásmo ISM 24 GHz | volně použitelné pásmo 24,00–24,25 GHz, šířka 250 MHz
ploška (patch) | obdélník mědi nad zemní vrstvou desky, rezonující na délce
| kolem půl vlnové délky v laminátu
sériově napájená řada | několik plošek za sebou na jednom vedení; dává úzký svazek
| podél řady
ekvivalentní svazek | kruhový svazek, který by dal stejný dvoucestný diagram, kdyby
| ho měl vysílač i přijímač
koutový odražeč | tři navzájem kolmé desky, které vracejí odraz ke zdroji; bodový
| cíl se známým radarovým průřezem
prázdná scéna | záznam bez cíle, který ukáže odraz okolí v buňce cíle
SWD | dvouvodičové ladicí rozhraní procesorů ARM Cortex-M
ochrana čtení | zámek paměti mikrokontroléru; obvykle ho zruší jen smazání
| celé paměti
diferenciální záznam | dva záznamy sběrnice, které se liší jedním nastavením; jejich
| rozdíl ukáže význam registrů

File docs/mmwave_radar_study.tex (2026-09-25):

% ---------------------------------------------------------------------------
% Skyren — mmWave Radar Study
% Build:  lualatex mmwave_radar_study.tex   (dvakrát)
% ---------------------------------------------------------------------------
\documentclass[czech]{skyren}
\usepackage{amsmath}
\usepackage{amssymb}   % \varnothing pro průměr

% Značky ve fotkách modulů: štítek antény a číslo součástky. \cislo{n} sází
% stejné číslo do textu a tabulek.
\tikzset{
  foto/.style={font=\fontsize{7.5}{9}\selectfont, fill=skyrenGround,
    draw=skyrenInk, line width=0.5pt, inner sep=1.5pt},
  cislo/.style={circle, fill=skyrenInk, text=skyrenGround, inner sep=0pt,
    minimum size=4mm, font=\fontsize{7}{7}\selectfont\bfseries},
}
\newcommand{\cislo}[1]{\tikz[baseline=(c.base)]\node[cislo, minimum size=3.4mm,
  font=\fontsize{6.5}{6.5}\selectfont\bfseries] (c) {#1};}

\skyrendoctitle{mmWave Radar Study}
\skyrenstudytype{TECHNICKÁ STUDIE}
\skyrentitle{Levný radarový dálkoměr pro rychlé cíle}
\skyrensubtitle{Od rozebraného laserového dálkoměru k~24GHz FMCW senzoru
o~průměru 35\,mm za jednotky eur}

\skyrenaudience{Vývojář elektroniky nebo konstruktér se základy
vysokofrekvenční techniky (návrh patch antén, vedení, polarizace), který
radar dosud nenavrhoval. Tři teoretické díly (signál, odraz, anténa)
vysvětlují látku od základů i~s~odvozením; kdo ji zná, může číst jen souhrny
na začátku a~na konci dílů a~pokračovat dílem Návrh.}

\skyrenmeta{%
  \metaitem{Projekt}{mmWave Radar}\hfill
  \metaitem{Revize}{R3}\hfill
  \metaitem{Datum}{Září 2026}\hfill
  \metaitem[0.2]{Klasifikace}{Interní}%
}

\begin{document}

\skyrenmaketitle

\begin{skyrensummary}
Vzdálenost k~plošnému cíli do 5\,m při vzájemné rychlosti až 240\,m/s
změří \textbf{24GHz FMCW radar s~trojúhelníkovou rampou}, jednou anténou
o~průměru 35\,mm a~tištěnou čočkou za \textbf{zhruba 4--7\,€} materiálu.
Hladké povrchy změří pod 1\,cm; na drsných rozhoduje \textbf{speckle} --- po
průměrování přes 1,2\,m přiblížení kolem 3\,cm u~kolmé zdi a~5--6\,cm při
náklonu 15$^\circ$, kde zadání 5\,cm splní až užší svazek. Fotky modulů
HLK-LD2450 a~LD2451 ukázaly, že radarový čip nese potisk Hi-Link a~že
vysílač a~přijímač LD2450 leží 23\,mm od sebe; vývoj proto poběží
s~\textbf{čočkou jen nad přijímačem}, která dá stejný rozpočet výkonu jako
cílový návrh. Praktický díl to převádí na osm etap s~kritérii; rozhodují
dvě --- ovládnout čip vlastním firmwarem a~změřit speckle na skutečné zdi.
\end{skyrensummary}

\begin{skyrennote}[Jak číst tento dokument]
\textbf{Boxy se štítkem} označují typ sdělení: \textsc{poznámka} kontext
navíc, \textsc{tip} zkratku, \textsc{úskalí} častou chybu, \textsc{pozor}
nevratný krok, \textsc{příklad} konkrétní výpočet. \textsc{Na jeden pohled}
otevírá díl, \textsc{co z~toho plyne} ho uzavírá. \skyrencmd{Mono písmo}
značí hodnotu nebo označení dílu, číslo v~kroužku \cislo{1} součástku na
fotce modulu. Revize R3 doplňuje R2 o~rozbor modulů HLK z~fotografií (díl
Rozbor) a~o~praktický plán (díl Praxe), který nahradil dřívější Postup.
Čísla v~R3 pocházejí z~výpočtů, simulací a~fotografií, ne z~měření radarem.
\end{skyrennote}

\tableofcontents
\vspace{10mm}

% ===========================================================================
\skyrenchapter[\skyrenmodeexplanation]{Východiska}{Zadání a proč ne optika}
% ===========================================================================

\begin{skyrenglance}
Rozebraný Parkside PLEM 20 A4 je fázový měřák s~uzavřeným ASICem --- slepá
ulička. Zadání 240\,m/s pak vyřadilo optiku jako princip: limitem přestává
být přesnost jednoho měření a~stává se jím vzorkovací frekvence. Rozhodující
pro návrh jsou ale až další dvě podmínky --- cena a~velikost.
\end{skyrenglance}

\section{Co jsme rozebrali}
\skyrenlead{Teardown laserového dálkoměru Parkside a~důvod, proč se v~něm
nedá pokračovat.}

Výchozím bodem byl rozebraný dálkoměr \skyrencmd{Parkside PLEM 20 A4}
(model \skyrencmd{HG06724}, výroba 2020/06). Měřicí modul je samostatná deska
zhruba 13\,$\times$\,25\,mm: laserová dioda v~pouzdře TO, přijímací lavinová
fotodioda ve~stíněné komoře, krystal a~jeden ASIC v~pouzdře QFN s~potiskem
\skyrencmd{LGSM4 / N1PA45.00-24}. K~hlavní desce vede osmipinový plochý spoj.

Přístroj neměří dobu letu pulzu, ale \skyrenterm{fázový posuv} spojitě
modulovaného svazku. Celý měřicí řetězec je uvnitř ASICu se zákaznickým
označením bez veřejného datového listu. Odposlech plochého spoje by dal
kontrolu nad rozhraním, ne nad měřením: frekvence i~integrační čas zůstávají
zadrátované v~čipu. Radarové moduly HLK, na kterých stojí další vývoj,
rozebírá díl Rozbor.

\section{Zadání}
\skyrenlead{Pět požadavků. Poslední dva, cena a~velikost, rozhodly o~návrhu
nejvíc.}

Zadání se během studie zpřesňovalo. Tabulka uvádí jeho konečný stav:

\begin{skyrentable}{3}{Konečné zadání. Cena a~velikost jsou priority, které
určil zadavatel.}
\skyrenth{Parametr} & \skyrenth{Hodnota} & \skyrenth{Poznámka} \\
\midrule
Cíl & jeden, plošný & kov, plech, beton, zeď, dřevo \\
Přesnost & $\approx$\,5\,cm na 5\,m & rozšíření: $<$\,3\,cm do 30\,m \\
Rychlost & až 240\,m/s & vzájemná, cíl se přibližuje \\
Cena & ideálně 25\,€, max. 50\,€ & materiál na kus; \textbf{priorita č.~1} \\
Velikost & kruh $\varnothing$\,35\,mm, co nejmenší & \textbf{priorita č.~2} \\
\end{skyrentable}

Důležité je, že jde o~\emph{jeden} cíl. Nepotřebujeme oddělit dva odrazy
blízko sebe (\skyrenterm{rozlišení}), stačí přesně určit polohu jednoho
(\skyrenterm{přesnost}). Teoretické díly ukazují, že přesnost může být
o~řád lepší než rozlišení.

\section{Co udělá rychlost 240\,m/s}
\skyrenlead{Převod rychlosti na požadavek na vzorkovací frekvenci.}

Mezi dvěma vzorky urazí cíl dráhu, kterou žádné přesnější měření
neodstraní --- jen vyšší frekvence:

\begin{skyrentable}{3}{Dráha mezi dvěma vzorky při 240\,m/s.}
\skyrenth{Vzorkovací frekvence} & \skyrenth{Perioda} & \skyrenth{Dráha mezi vzorky} \\
\midrule
100\,Hz & 10\,ms & 2,40\,m \\
1\,kHz & 1\,ms & 24\,cm \\
4\,kHz & 250\,\textmu s & 6\,cm \\
10\,kHz & 100\,\textmu s & 2,4\,cm \\
\end{skyrentable}

Z~toho plynou tři požadavky: vzorkovací frekvence aspoň 1\,kHz,
integrační čas jednoho měření pod 1\,ms a~latence celé cesty v~jednotkách
milisekund. Měření staré 5\,ms je 1,2\,m mimo.

\begin{skyrengotcha}[Přesnost z~datového listu nestačí]
Údaj „$\pm$\,3\,cm“ v~datovém listu popisuje rozptyl jednoho měření za
ideálních podmínek. Při 240\,m/s bývá větší chybou stáří vzorku. Tu datový
list neuvede, protože závisí na vaší rychlosti --- spočítejte ji z~frekvence
a~latence.
\end{skyrengotcha}

\section{Proč ne optika}
\skyrenlead{Jediný vyhovující optický dálkoměr je o~řád dražší, než
dovoluje rozpočet.}

Přímé měření doby letu (dToF) splní požadavek na frekvenci jen u~výjimek.
\skyrencmd{LightWare SF30/D} měří katalogově 0,2 až 200\,m s~frekvencí až
20\,000 měření za sekundu. Rychlostí by zadání splnil, cenou ale patří mezi
měřicí techniku, ne mezi součástky. Levné senzory (\skyrencmd{VL53Lxx},
\skyrencmd{TMF8828}, \skyrencmd{TF-Luna}) běží na desítkách až stovkách Hz.
\skyrencmd{Broadcom AFBR-S50MV85G} zvládne až 3000 snímků za sekundu, ale
dosah má kolem 10\,m. S~rozpočtem 25\,€ proto zbývá radar.

\begin{skyrentakeaway}
Optika na tomhle zadání neselhala na přesnosti, ale na kombinaci frekvence
a~ceny. O~dalším návrhu rozhodly cena a~velikost, ne fyzikální meze měření.
\end{skyrentakeaway}

% ===========================================================================
\skyrenchapter[\skyrenmodeexplanation]{Teorie: signál}{Signál FMCW}
% ===========================================================================

\begin{skyrenglance}
FMCW převádí vzdálenost na kmitočet. Vzdálenost vypadne z~polohy vrcholu
ve spektru jedné rampy; rozlišení určuje šířka pásma, přesnost odstup
signálu od šumu. Pohyb cíle posune odhad o~desítky centimetrů, trojúhelníková
rampa ten posuv vyruší. U~blízkých cílů rozhoduje vazba vysílače do
přijímače a~blikavý šum.
\end{skyrenglance}

\section{Chirp a~rozdílová frekvence}
\skyrenlead{Model signálu, ze kterého plyne všechno ostatní.}

\skyrenterm{FMCW} (frequency-modulated continuous wave) vysílá spojitý signál,
jehož kmitočet lineárně roste; jedné takové rampě se říká \skyrenterm{chirp}.
Se sklonem $S = B/T$, kde $B$ je šířka přeladění a~$T$ délka chirpu, má
vysílaný signál fázi
\[
\varphi_\mathrm{t}(t) = 2\pi\left(f_0 t + \tfrac{1}{2} S t^2\right)
\]
Odraz od cíle ve vzdálenosti $R$ přijde zpožděný o~dobu letu $\tau = 2R/c$.
Směšovač vynásobí vyslaný a~přijatý signál a~dolní propust nechá jen
rozdílovou složku:
\[
s_\mathrm{b}(t) = A\cos\!\left(2\pi S\tau\,t + 2\pi f_0\tau - \pi S\tau^2\right)
\]
Je to harmonický signál s~\skyrenterm{rozdílovou frekvencí}
\[
f_\mathrm{b} = S\tau = \frac{2RB}{cT}
\]
a~s~fází $4\pi R/\lambda$, která se mění už při posunu cíle o~zlomek vlnové
délky. Člen $\pi S\tau^2$ je na 5\,m pod 0,1\,rad a~konstantní, takže ho lze
zanedbat.

\begin{skyrenfigure}{Princip FMCW. Vyslaný chirp (plná čára) stoupá lineárně;
odraz (čárkovaně) je jeho kopie posunutá o~dobu letu $\tau$. Svislá vzdálenost
mezi čarami je rozdílová frekvence $f_\mathrm{b}$ --- po celou rampu konstantní
a~přímo úměrná vzdálenosti cíle.}{fig:fmcw}
\begin{tikzpicture}[x=1.2mm, y=1.2mm, line width=1pt,
  every node/.style={font=\fontsize{8}{10}\selectfont}]
  \draw[skyrenNeutral600, line width=0.6pt, ->] (0,0) -- (78,0)
    node[anchor=north east] {čas};
  \draw[skyrenNeutral600, line width=0.6pt, ->] (0,0) -- (0,32)
    node[anchor=south west] {kmitočet};
  \draw[skyrenInk] (0,2) -- (30,26);
  \draw[skyrenInk] (30,2) -- (60,26);
  \draw[skyrenNeutral600, dashed, line width=0.9pt] (7,2) -- (37,26);
  \draw[skyrenNeutral600, dashed, line width=0.9pt] (37,2) -- (60,20.4);
  \draw[skyrenRed, line width=1pt] (22,13.6) -- (22,19.6);
  \node[anchor=west, skyrenRed] at (23.5,16.6) {$f_\mathrm{b}$};
  \draw[skyrenNeutral600, line width=0.6pt] (0,-4) -- (7,-4);
  \draw[skyrenNeutral600, line width=0.6pt] (0,-2.5) -- (0,-5.5);
  \draw[skyrenNeutral600, line width=0.6pt] (7,-2.5) -- (7,-5.5);
  \node[anchor=north] at (3.5,-5) {$\tau$};
  \draw[skyrenNeutral600, line width=0.6pt] (66,2) -- (66,26);
  \draw[skyrenNeutral600, line width=0.6pt] (64.5,2) -- (67.5,2);
  \draw[skyrenNeutral600, line width=0.6pt] (64.5,26) -- (67.5,26);
  \node[anchor=west] at (68,14) {$B$};
  \draw[skyrenInk] (0,-13) -- (7,-13);
  \node[anchor=west] at (8.5,-13) {vyslaný chirp};
  \draw[skyrenNeutral600, dashed, line width=0.9pt] (34,-13) -- (41,-13);
  \node[anchor=west] at (42.5,-13) {přijatý odraz};
\end{tikzpicture}
\end{skyrenfigure}

Na obr.~\ref{fig:fmcw} je vidět, že rozdíl mezi čarami je po celou rampu
konstantní. Pro návrhový profil ($B = 250$\,MHz, $T = 10$\,\textmu s) vychází
$f_\mathrm{b}$ na 1\,m 167\,kHz, na 5\,m 833\,kHz a~na 8\,m 1,33\,MHz.

\section{Od vzorků ke vzdálenosti}
\skyrenlead{Okno, FFT, doplnění nulami a~interpolace vrcholu --- a~kolik
která část přispívá k~chybě.}

Mezifrekvenční signál se během chirpu navzorkuje; při 4\,MSPS a~10\,\textmu s
to je $N = 40$ vzorků. Vzorkování \skyrenterm{I/Q} (dva kanály posunuté
o~90$^\circ$) dává komplexní signál, který rozliší znaménko kmitočtu. To je
potřeba pod 0,23\,m, kde dopplerovský posuv převýší rozdílovou frekvenci
(viz dále).

Vzorky se vynásobí \skyrenterm{oknem}. Hannovo okno potlačí postranní laloky
spektra na $-31$\,dB, takže silná vazba vysílače do přijímače nebo druhý
odraz neprosáknou do buňky cíle. Cenou je dvakrát širší hlavní lalok
a~šumová šířka 1,5 buňky místo jedné.

Pak následuje rychlá Fourierova transformace (FFT). Doplnění nulami ze 40 na
64 nebo 128 bodů zhustí vzorkování spektra, rozlišení ale nezlepší.
Vrchol leží mezi body FFT; jeho polohu dopočítá
\skyrenterm{parabolická interpolace} logaritmu amplitudy ve třech bodech
$k-1, k, k+1$ s~hodnotami $\alpha, \beta, \gamma$ v~dB:
\[
\delta = \frac{1}{2}\cdot\frac{\alpha-\gamma}{\alpha-2\beta+\gamma}, \qquad
\hat R = (k+\delta)\cdot\frac{c\,f_\mathrm{s}}{2\,S\,M}
\]
kde $f_\mathrm{s}$ je vzorkovací frekvence a~$M$ délka FFT. Simulace
s~Hannovým oknem dala systematickou chybu interpolace nejvýš 2\,mm pro
$M = 64$ a~0,2\,mm pro $M = 128$. Interpolace tedy do rozpočtu chyby
nepřispívá.

\section{Rozlišení a~přesnost}
\skyrenlead{Rozlišení určuje šířka pásma, přesnost na jeden cíl určuje odstup
signálu od šumu.}

\skyrenterm{Rozlišení} je nejmenší vzdálenost, na které radar oddělí dva
cíle. Závisí jen na šířce přeladění:
\[
\Delta R = \frac{c}{2B}
\]
Ve volném pásmu \skyrencmd{24,00--24,25\,GHz} je $B = 250$\,MHz, takže
$\Delta R = 60$\,cm. Lepší rozlišení by vyžadovalo jiné pásmo: 4\,GHz
v~pásmu 60\,GHz dává 3,75\,cm.

Pro jeden cíl je podstatná \skyrenterm{přesnost}. Teoretickou nejmenší
chybu udává \skyrenterm{Cramér--Raova mez} pro odhad kmitočtu harmonického
signálu v~šumu:
\[
\sigma_R \geq \frac{\sqrt{6}}{2\pi}\cdot\frac{\Delta R}{\sqrt{\mathrm{SNR}}}
\approx 0{,}39\,\frac{\Delta R}{\sqrt{\mathrm{SNR}}}
\]
kde SNR je odstup signálu od šumu po FFT (energie signálu za chirp
k~spektrální hustotě šumu). Hannovo okno s~parabolickou interpolací dosahuje
podle simulace $\sigma_R \approx 0{,}6\,\Delta R/\sqrt{\mathrm{SNR}}$.

\begin{skyrenexample}
Buňka 60\,cm, SNR 30\,dB (1000$\times$): mez dává 0,74\,cm, praktický
odhad 1,1\,cm, simulace 1,2\,cm. Při 40\,dB vychází prakticky 0,35\,cm.
Rozlišení 60\,cm tedy přesnosti na centimetry nebrání, pokud je signálu
dost a~cíl je jeden.
\end{skyrenexample}

Fáze vrcholu $4\pi R/\lambda$ nese ještě jemnější informaci, ale
s~nejednoznačností $\lambda/2$, na 24\,GHz 6,2\,mm. Hrubý odhad z~FFT není
dost přesný, aby ji rozbalil absolutně. Fáze proto dává jen
\emph{relativní} změnu vzdálenosti při spojitém sledování cíle.

\section{Dopplerův posuv a~trojúhelníková rampa}
\skyrenlead{Při 240\,m/s posune pohyb cíle odhad o~23\,cm. Střídání rampy
nahoru a~dolů ten posuv vyruší a~navíc změří rychlost.}

Přibližující se cíl zvýší kmitočet odrazu o~\skyrenterm{dopplerovský posuv}
$f_\mathrm{d} = 2v/\lambda$; při 240\,m/s a~$\lambda = 12{,}4$\,mm to je
38,6\,kHz. U~stoupající rampy se tím rozdílová frekvence zmenší,
u~klesající zvětší:
\[
f_{\mathrm{b}\uparrow} = S\tau - f_\mathrm{d}, \qquad
f_{\mathrm{b}\downarrow} = S\tau + f_\mathrm{d}
\]
Převedeno na vzdálenost je každý z~obou odhadů posunutý o
\[
\Delta R_\mathrm{D} = \frac{v\,c\,T}{\lambda\,B}
\]
což je při chirpu 10\,\textmu s \textbf{23\,cm}, při 25\,\textmu s už 58\,cm.

\begin{skyrenfigure}{Trojúhelníková rampa a~přibližující se cíl. Odraz
(čárkovaně) je zpožděný o~$\tau$ a~posunutý nahoru o~$f_\mathrm{d}$. Na
stoupající rampě se rozdílová frekvence zmenší, na klesající zvětší; průměr
obou je bez Dopplerova posuvu.}{fig:troj}
\begin{tikzpicture}[x=1.2mm, y=1.2mm, line width=1pt,
  every node/.style={font=\fontsize{8}{10}\selectfont}]
  \draw[skyrenNeutral600, line width=0.6pt, ->] (0,0) -- (70,0)
    node[anchor=north east] {čas};
  \draw[skyrenNeutral600, line width=0.6pt, ->] (0,0) -- (0,33)
    node[anchor=south west] {kmitočet};
  \draw[skyrenInk] (0,2) -- (30,26) -- (60,2);
  \draw[skyrenNeutral600, dashed, line width=0.9pt] (6,4.5) -- (36,28.5) -- (60,9.3);
  \draw[skyrenRed, line width=1pt] (20,15.7) -- (20,18);
  \node[anchor=east, skyrenRed] at (19,16.9) {$f_{\mathrm{b}\uparrow}$};
  \draw[skyrenRed, line width=1pt] (48,11.6) -- (48,18.9);
  \node[anchor=west, skyrenRed] at (49,15.2) {$f_{\mathrm{b}\downarrow}$};
  \draw[skyrenInk] (0,-6) -- (7,-6);
  \node[anchor=west] at (8.5,-6) {vyslaná rampa};
  \draw[skyrenNeutral600, dashed, line width=0.9pt] (34,-6) -- (41,-6);
  \node[anchor=west] at (42.5,-6) {odraz od přibližujícího se cíle};
\end{tikzpicture}
\end{skyrenfigure}

Z~dvojice odhadů $R_\uparrow = R - \Delta R_\mathrm{D}$
a~$R_\downarrow = R + \Delta R_\mathrm{D}$ (obr.~\ref{fig:troj}) plyne
\[
R = \frac{R_\uparrow + R_\downarrow}{2}, \qquad
v = \frac{\lambda B}{2cT}\,\bigl(R_\downarrow - R_\uparrow\bigr)
\]
Vzdálenost platí pro střed dvojice chirpů, tam patří i~časová značka. Během
jednoho chirpu se cíl posune o~$vT = 2{,}4$\,mm, což je zanedbatelné.
Dopplerovská FFT přes více chirpů, obvyklá u~automobilových radarů, tu
nefunguje: s~periodou chirpů kolem 25\,\textmu s je nejvyšší jednoznačná
rychlost $\lambda/4T_\mathrm{c} \approx 124$\,m/s a~240\,m/s by se přetočila.

\section{Šum a~odstup signálu od šumu}
\skyrenlead{Tepelný šum v~šířce jedné buňky a~proč fázový šum oscilátoru na
metrech skoro nevadí.}

Šum připadající na jednu buňku spektra je tepelný šum v~šumové šířce okna,
zvětšený o~šumové číslo přijímače $F$:
\[
N = kT_0 \cdot \frac{\mathrm{ENBW}}{T} \cdot F
\quad\Rightarrow\quad
N_\mathrm{dBm} = -174 + 10\log_{10}\frac{1{,}5}{T} + F_\mathrm{dB}
\]
Pro chirp 10\,\textmu s a~šumové číslo 15\,dB (odhad, datový list čipu
nemáme) vychází \mbox{$N \approx -107$\,dBm}.

Fázový šum oscilátoru se ve směšovači z~velké části odečte, protože vysílaný
i~referenční signál pocházejí ze stejného oscilátoru. Zbytek je úměrný
$2\sin(\pi f_\mathrm{m}\tau)$, kde $f_\mathrm{m}$ je odstup od nosné. Na
5\,m je $\tau = 33$\,ns a~potlačení vychází $-14$\,dB při 1\,MHz a~$-34$\,dB
při 100\,kHz. Na krátké vzdálenosti tedy kvalita oscilátoru rozhoduje málo.

\section{Blízký dosah: vazba, blikavý šum a~horní propust}
\skyrenlead{Silná vazba vysílače do přijímače, blikavý šum a~velká dynamika
se řeší jedním filtrem --- a~ten má mít pro plošný cíl sklon 20\,dB na
dekádu, ne 40.}

S~jednou anténou pro vysílání i~příjem teče část vysílaného výkonu přímo do
přijímače: přes konečnou izolaci vazebníku (typicky kolem 25\,dB), přes odraz
na anténě a~přes odrazy na čočce. Tato vazba sedí u~nulové rozdílové
frekvence a~může dosáhnout $-15$ až $-20$\,dBm na vstupu přijímače.
Kompresní bod přijímače integrovaného čipu neznáme; pokud je kolem
$-15$\,dBm, hrozí zahlcení. Proto je u~jedné antény klíčové dobré
impedanční přizpůsobení ($S_{11} < -20$\,dB).

Blikavý šum (1/$f$) směšovače roste pod zhruba 100\,kHz. Krátký chirp drží
rozdílovou frekvenci i~na 1\,m (167\,kHz) nad touto oblastí.

Výkon odrazu od plošného cíle klesá s~$R^2$ (díl Odraz od plošného cíle), amplituda tedy
s~$1/R$, a~protože $f_\mathrm{b} \propto R$, klesá amplituda úměrně
$1/f_\mathrm{b}$. Horní propust prvního řádu s~mezním kmitočtem nad pásmem
měření má v~pásmu zisk úměrný $f$, tedy \textbf{+20\,dB na dekádu}: srovná
úroveň signálu přes celý rozsah vzdáleností a~současně potlačí vazbu
u~nulového kmitočtu. Pro bodový cíl ($R^{-4}$) by bylo potřeba +40\,dB na
dekádu.

\begin{skyrentakeaway}
Vzdálenost dá jedna rampa a~jedna malá FFT; interpolace vrcholu je přesná na
milimetry. Dopplerův posuv 23\,cm vyruší trojúhelníková rampa. Přesnost pak
určuje odstup signálu od šumu --- a~u~plošného cíle, jak ukáže další díl,
hlavně geometrie odrazu.
\end{skyrentakeaway}

% ===========================================================================
\skyrenchapter[\skyrenmodeexplanation]{Teorie: odraz}{Odraz od plošného cíle}
% ===========================================================================

\begin{skyrenglance}
Hladká plocha se chová jako zrcadlo: odraz přichází z~malé skvrny kolem
paty kolmice a~radar změří kolmou vzdálenost na milimetry. Drsná plocha
rozptyluje: přispívá celá stopa svazku, odhad se posune a~náhodně kolísá
(speckle). Rozhoduje drsnost vůči vlnové délce, ne materiál.
\end{skyrenglance}

\section{Tři modely odrazu}
\skyrenlead{Bodový cíl, zrcadlová plocha a~drsná plocha mají tři různé
radarové rovnice.}

\textbf{Bodový cíl} s~radarovým průřezem $\sigma$ je výchozí případ radarové
rovnice:
\[
P_\mathrm{r} = \frac{P_\mathrm{t}\,G^2\lambda^2\,\sigma}{(4\pi)^3 R^4}
\]

\textbf{Hladká rovina} větší než první Fresnelova zóna se chová jako zrcadlo.
Radar v~ní vidí svůj obraz ve vzdálenosti $2R$, takže
\[
P_\mathrm{r} = \frac{P_\mathrm{t}\,G^2\lambda^2\,|\Gamma|^2}{(4\pi)^2 (2R)^2}
\]
kde $\Gamma$ je činitel odrazu materiálu. Odraz vzniká v~\skyrenterm{první
Fresnelově zóně}, skvrně o~poloměru $\sqrt{\lambda R/2}$ kolem paty kolmice
z~radaru na rovinu. Na 5\,m to je 18\,cm, zatímco stopa svazku 22$^\circ$ má
poloměr kolem 1\,m. Zeď je tedy pro radar „nekonečné zrcadlo“.

\textbf{Drsná rovina} rozptyluje difúzně a~každý kousek plochy přispívá
podle \skyrenterm{koeficientu zpětného rozptylu} $\sigma^0$ (m$^2$ na
m$^2$ plochy). Efektivní průřez je $\sigma = \sigma^0 R^2 \Omega_\mathrm{ef}$,
kde $\Omega_\mathrm{ef}$ je prostorový úhel svazku vážený dvoucestným
diagramem; pro gaussovský svazek s~šířkou $\theta_3$ platí
$\Omega_\mathrm{ef} = \pi\theta_3^2/(8\ln 2)$. Protože zisk antény
$G \propto 1/\theta_3^2$, vychází
\[
P_\mathrm{r} \propto \frac{G}{R^2}
\]
Oba plošné případy tedy klesají s~$R^2$, ne s~$R^4$. U~drsné plochy navíc
větší anténa signál skoro nezlepší, protože užší svazek ozáří menší plochu.

\section{Hladký, nebo drsný?}
\skyrenlead{O~chování plochy rozhoduje drsnost ve srovnání s~vlnovou délkou.
Na 24\,GHz leží hranice kolem 1,5\,mm.}

Nerovnosti o~střední výšce $h$ rozfázují odražené vlny. Zrcadlová
(koherentní) složka odrazu klesne podle \skyrenterm{Rayleighova kritéria}
o~faktor
\[
\rho = \exp\!\left[-\left(\frac{4\pi h\cos\theta_\mathrm{i}}{\lambda}\right)^2\right]
\]
kde $\theta_\mathrm{i}$ je úhel dopadu. Na 24\,GHz to dává pokles o~1,1\,dB
při $h = 0{,}5$\,mm, 4,4\,dB při 1\,mm, 18\,dB při 2\,mm a~40\,dB při 3\,mm.
Obvyklá hranice je $h \approx \lambda/8 = 1{,}6$\,mm.

\begin{skyrentable}{4}{Typické povrchy na 24\,GHz. Drsnosti a~permitivity
jsou orientační hodnoty, ne měření.}
\skyrenth{Povrch} & \skyrenth{Drsnost $h$} & \skyrenth{Chování} & \skyrenth{$|\Gamma|$ kolmo} \\
\midrule
plech & $\ll$\,0,1\,mm & zrcadlové & 1 (0\,dB) \\
hladký beton, omítka & $\approx$\,0,5--1\,mm & převážně zrcadlové & $\approx$\,0,40 ($-8$\,dB) \\
hoblované dřevo & $<$\,0,5\,mm & zrcadlové & $\approx$\,0,17 ($-15$\,dB) \\
sádrokarton & $<$\,0,5\,mm & zrcadlové & $\approx$\,0,25 ($-12$\,dB) \\
řezané dřevo & $\approx$\,1--2\,mm & smíšené & $\approx$\,0,17 \\
hrubý beton, cihla, kámen & $\approx$\,2--5\,mm & difúzní & --- \\
\end{skyrentable}

Činitel odrazu při kolmém dopadu je $\Gamma = (1-\sqrt{\varepsilon_\mathrm{r}})/(1+\sqrt{\varepsilon_\mathrm{r}})$.
Pro beton s~$\varepsilon_\mathrm{r} \approx 5{,}5$ vychází 0,40, pro suché
dřevo s~$\varepsilon_\mathrm{r} \approx 2$ jen 0,17. Dřevo je tedy nejslabší
zrcadlo, ale rozpočet výkonu v~dílu Návrh ukáže, že i~tak zbývá přes
40\,dB odstupu od šumu.

\section{Zrcadlový odraz měří kolmou vzdálenost}
\skyrenlead{Hladká plocha nemá žádný posun od stopy svazku. Při náklonu ale
měří jinou vzdálenost, než je vzdálenost v~ose, a~slábne.}

Protože zrcadlový odraz přichází jen z~první Fresnelovy zóny kolem paty
kolmice, radar změří \emph{kolmou vzdálenost k~rovině} $R_\perp = R\cos\alpha$,
kde $\alpha$ je náklon plochy vůči ose senzoru. Stopa svazku se neuplatní
a~chyba je daná jen šumem.

Při náklonu leží pata kolmice mimo osu svazku a~odraz zeslábne podle
dvoucestného diagramu. Pro svazek 22$^\circ$ je to $-6$\,dB při
11$^\circ$, $-11$\,dB při 15$^\circ$, $-20$\,dB při 20$^\circ$ a~$-31$\,dB
při 25$^\circ$. Hladký plech nakloněný o~víc než zhruba 20$^\circ$ proto
nevrátí skoro nic --- nemá difúzní složku, která by zbyla.

\begin{skyrennote}[Kterou vzdálenost vlastně měříme]
Při náklonu 15$^\circ$ je na 5\,m rozdíl mezi kolmou vzdáleností a~vzdáleností
v~ose kolem 17\,cm. Není to chyba měření. U~hladkých ploch radar měří
kolmou vzdálenost, u~drsných zhruba vzdálenost v~ose. Aplikace musí vědět,
kterou z~nich potřebuje.
\end{skyrennote}

\section{Stopa svazku a~posun odhadu}
\skyrenlead{U~drsné plochy přispívá celá stopa. Její zakřivení vůči radaru
posune odhad za skutečnou vzdálenost.}

\begin{skyrenfigure}{Stopa svazku na zdi (bokorys, úhel zveličený). Kružnice
konstantní vzdálenosti (červeně) protíná zeď jen v~ose; okraje stopy leží
dál o~$\Delta R$. U~drsné plochy padnou všechny příspěvky do jedné buňky
a~posunou odhad za kolmou vzdálenost.}{fig:stopa}
\begin{tikzpicture}[x=1.1mm, y=1.1mm, line width=1pt,
  every node/.style={font=\fontsize{8}{10}\selectfont}]
  \draw[skyrenInk, fill=skyrenNeutral400] (-6,-3) rectangle (0,3);
  \node[anchor=east] at (-7,0) {radar};
  \draw[skyrenNeutral600, line width=0.7pt] (0,0) -- (60,21.84);
  \draw[skyrenNeutral600, line width=0.7pt] (0,0) -- (60,-21.84);
  \draw[skyrenNeutral600, dashed, line width=0.7pt] (0,0) -- (60,0);
  \node[anchor=south] at (30,0.5) {$R$};
  \draw[skyrenRed, line width=0.9pt] (56.38,-20.52) arc[start angle=-20, end angle=20, radius=60];
  \draw[skyrenInk, line width=2.2pt] (60,-27) -- (60,27);
  \node[anchor=west] at (61.5,-24) {zeď};
  \draw[skyrenInk, line width=0.7pt] (56.38,20.52) -- (60,21.84);
  \node[anchor=south east] at (57,21.5) {$\Delta R$};
  \draw[skyrenNeutral600, line width=0.6pt] (14,0) arc[start angle=0, end angle=20, radius=14];
  \node[anchor=west] at (15,2.6) {$\theta/2$};
\end{tikzpicture}
\end{skyrenfigure}

Vzdálenost k~bodu plochy ve směru $(\theta_x, \theta_y)$ od osy je pro plochu
nakloněnou o~$\alpha$ kolem osy $y$ přibližně
\[
R(\theta_x,\theta_y) \approx R\left[1 + \theta_x\tan\alpha
  + \theta_x^2\left(\tfrac{1}{2}+\tan^2\alpha\right) + \tfrac{1}{2}\theta_y^2\right]
\]
Rozdíly vzdáleností ve stopě jsou mnohem menší než buňka 60\,cm, takže vrchol
FFT leží ve výkonově váženém průměru vzdáleností. Pro gaussovský dvoucestný
diagram s~rozptylem $\sigma_\theta^2 = \theta_3^2/(16\ln 2)$ v~každé ose
lineární člen vypadne a~zbude \skyrenterm{posun od stopy svazku}
\[
b = R\,\sigma_\theta^2\,(1+\tan^2\alpha) = \frac{R\,\theta_3^2}{16\ln 2}\,(1+\tan^2\alpha)
\]
(obr.~\ref{fig:stopa}). U~kolmé zdi se simulace od vzorce liší o~méně než
desetinu, u~nakloněné do pětiny, zčásti kvůli statistickému rozptylu
simulace.
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

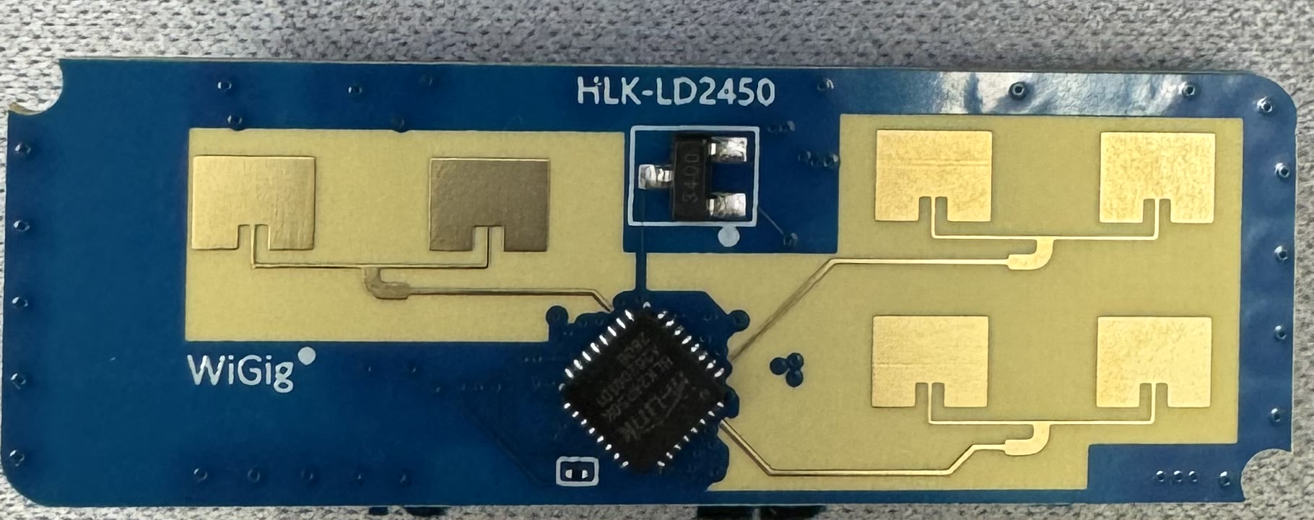
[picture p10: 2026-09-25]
docs/fig/ld2450_antena.jpg

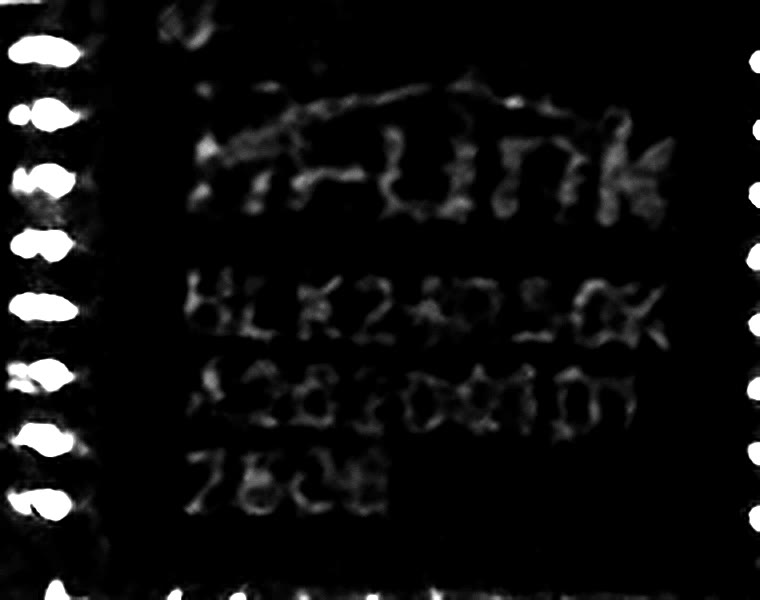
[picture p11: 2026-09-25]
docs/fig/ld2450_potisk.jpg

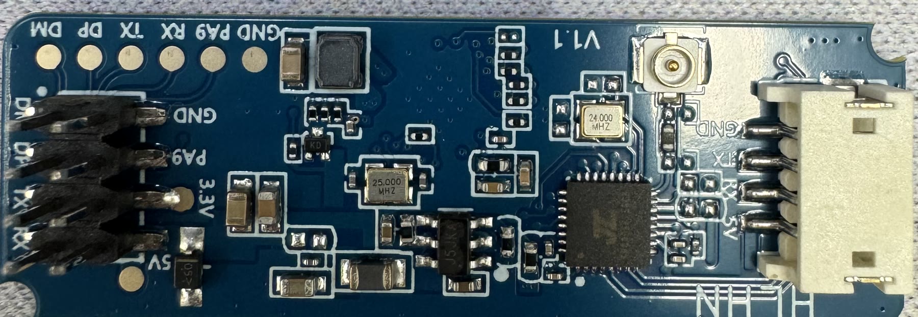
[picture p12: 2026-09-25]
docs/fig/ld2450_soucastky.jpg

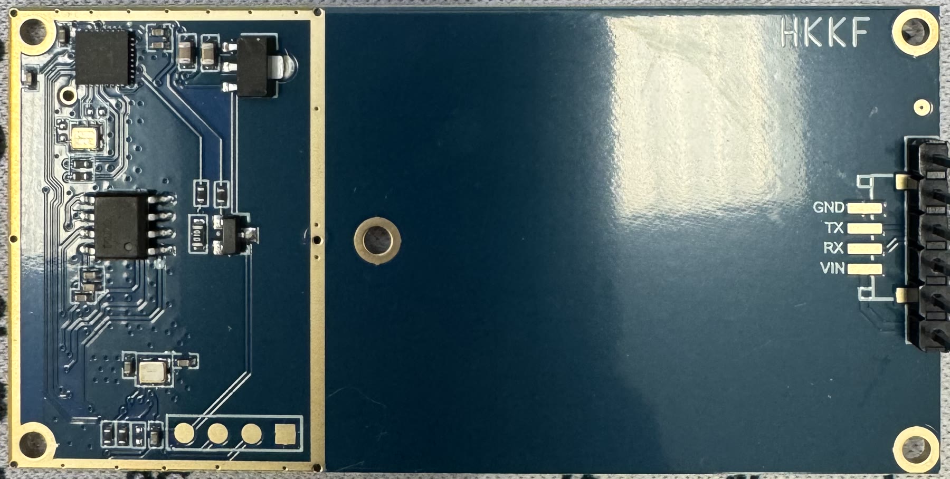
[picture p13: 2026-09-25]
docs/fig/ld2451_soucastky.jpg

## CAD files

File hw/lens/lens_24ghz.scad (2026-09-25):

// ---------------------------------------------------------------------------
// Hyperbolická plankonvexní čočka pro 24GHz radarový modul
//
// Hyperbolická plocha míří k modulu, rovná plocha k cíli.
// Fázový střed antény musí ležet ve vzdálenosti f pod vrcholem čočky.
// Profil: (n^2 - 1) z^2 + 2 (n - 1) f z - r^2 = 0
//
// Varianty pro vývoj na HLK-LD2450 (vysílač a přijímač ~23 mm od sebe):
//   sep > 0  dělená čočka: dvě poloviny apertury, každá s osou nad svou
//            anténou; osy leží na ose x ve vzdálenosti sep, šev v x = 0
//   cut > 0  plná čočka seříznutá rovně ve vzdálenosti cut od osy na
//            straně -x, aby nezakrývala sousední anténu (čočka jen nad Rx)
// ---------------------------------------------------------------------------

n      = 1.52;  // index lomu: HDPE 1.52, PTFE 1.45, PETG ~1.62, PLA ~1.65 (ověř měřením)
D      = 35;    // průměr apertury [mm]
f      = 28;    // vzdálenost fázového středu antény od vrcholu čočky [mm]
t_edge = 1.5;   // nejmenší tloušťka na okraji [mm]
sep    = 0;     // rozestup os dělené čočky [mm]; 0 = plná čočka (LD2450: 23)
cut    = 0;     // seříznutí plné čočky [mm od osy]; 0 = bez seříznutí (LD2450: 12)
steps  = 80;    // jemnost profilu

R = D / 2;
function sag(r) = (-(n - 1) * f + sqrt(pow((n - 1) * f, 2) + (n * n - 1) * r * r)) / (n * n - 1);

// Nejvzdálenější bod apertury od osy: u dělené čočky roh švu (0, ±R).
R_ext = sep > 0 ? sqrt(pow(sep / 2, 2) + R * R) : R;
T = sag(R_ext) + t_edge;

module body(rmax) {
  rotate_extrude($fn = 180) polygon(concat(
    [for (i = [0 : steps]) let (r = rmax * i / steps) [r, sag(r)]],
    [[rmax, T], [0, T]]
  ));
}

// Poloprostor x >= 0 (side = 1) nebo x <= 0 (side = -1), s rezervou v z.
module half_space(side) {
  translate([side > 0 ? 0 : -R - 1, -R - 1, -1]) cube([R + 1, 2 * R + 2, T + 2]);
}

if (sep > 0) {
  intersection() {
    translate([0, 0, -1]) cylinder(r = R, h = T + 2, $fn = 180);
    union() {
      intersection() { translate([-sep / 2, 0, 0]) body(R_ext); half_space(-1); }
      intersection() { translate([ sep / 2, 0, 0]) body(R_ext); half_space(1); }
    }
  }
} else if (cut > 0) {
  intersection() {
    body(R);
    translate([-cut, -R - 1, -1]) cube([R + cut + 1, 2 * R + 2, T + 2]);
  }
} else {
  body(R);
}

echo(str("Tloušťka na ose: ", T, " mm"));
echo(str("Výška od fázového středu antény po rovnou plochu: ", f + T, " mm"));

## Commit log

2026-09-22 Pivot to mmWave radar study; add typeset document
    Teardown of the Parkside PLEM 20 A4 ended as a dead end (phase-shift
    measurement behind a house-marked ASIC). The 240 m/s requirement then
    ruled out optical ranging as a principle, so the project becomes a
    feasibility study of 24 GHz single-chirp FMCW radar.
    - docs/mmwave_radar_study.tex — study, typeset with the Skyren LaTeX class
    - docs/skyren.cls, docs/fonts — symlinks into the template submodule
    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
2026-09-24 Add parametric 24 GHz hyperbolic lens model; ignore STL
    hw/lens/lens_24ghz.scad — plano-convex hyperbolic lens, D 35 mm,
    f 28 mm, index of refraction as a parameter (HDPE/PTFE/PETG/PLA).
    Generated STL files are build output and stay out of git.
    [lens_24ghz.scad]
2026-09-24 Study R2: 24 GHz FMCW design with full theory and simulations
    Rewrite of the study for the refined requirements (single extended
    target, ~5 cm at 5 m, 240 m/s, cost first, D 35 mm).
    - Theory: FMCW signal model, windowing and peak interpolation, CRB,
    Doppler bias and triangular ramp, noise and phase-noise range
    correlation, near range and IF high-pass slope
    - Reflection from extended targets: specular vs diffuse, Rayleigh
    roughness, Fresnel zone, footprint bias, speckle and averaging
    - Antenna and lens: aperture relations, Fermat derivation of the
    hyperbolic lens, losses, AR layer, feed offset, EIRP limit
    - Design: block diagram, profile, link and error budgets, cost
    - sim/: pure-Pyt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
2026-09-25 Study R3: HLK module teardown from photos and practical plan
    - New part "Rozbor": annotated photos of HLK-LD2450 and LD2451, antenna
    geometry (Tx-Rx ~23 mm on LD2450), component roles as hypotheses, and
    three lens configurations for development (none, lens over Rx only,
    split lens) with model predictions.
    - New part "Praxe" replaces "Postup": eight stages with outputs, pass
    criteria, two decision gates, equipment and transmit rules.
    - New appendix "Měřicí protokol" pairing each prediction with a blank
    measured column; formulas, sources and glossary extended.
    - Lens model gains `cut` (lens over Rx only) and `sep` (split lens).
    - Photo crops for typesetting in docs/fig/.
    Co-Autho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
    [lens_24ghz.scad]
2026-09-25 Add KiCad reverse-engineering projects for HLK-LD2450 and LD2451
    Two KiCad 10 projects for stage 2 of the practical plan (board mapping),
    drawn from the module photos and the vendor manuals:
    - hw/ld2450/, hw/ld2451/: schematic with every part identified in the
    photos, numbered as in the study's teardown part, with marking, role
    hypothesis and how to verify it. Only connector grounds are joined;
    other nets carry the connector prefix until probing merges them, so
    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
    [ld2450.kicad_sch, ld2451.kicad_sch]
2026-09-25 Remove KiCad reverse-engineering projects
    Not wanted in this repository. Drops hw/ld2450/, hw/ld2451/ and
    hw/lib/, their README rows and .gitignore entries, and the KiCad
    mentions in the study (stage 2 plan, input data). Study corrections
    from the vendor manuals stay.
    [ld2450.kicad_sch, ld2451.kicad_sch]
